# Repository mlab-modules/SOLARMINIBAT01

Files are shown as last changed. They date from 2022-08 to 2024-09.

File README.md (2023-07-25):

# SOLARMINIBAT01
<p float="left">
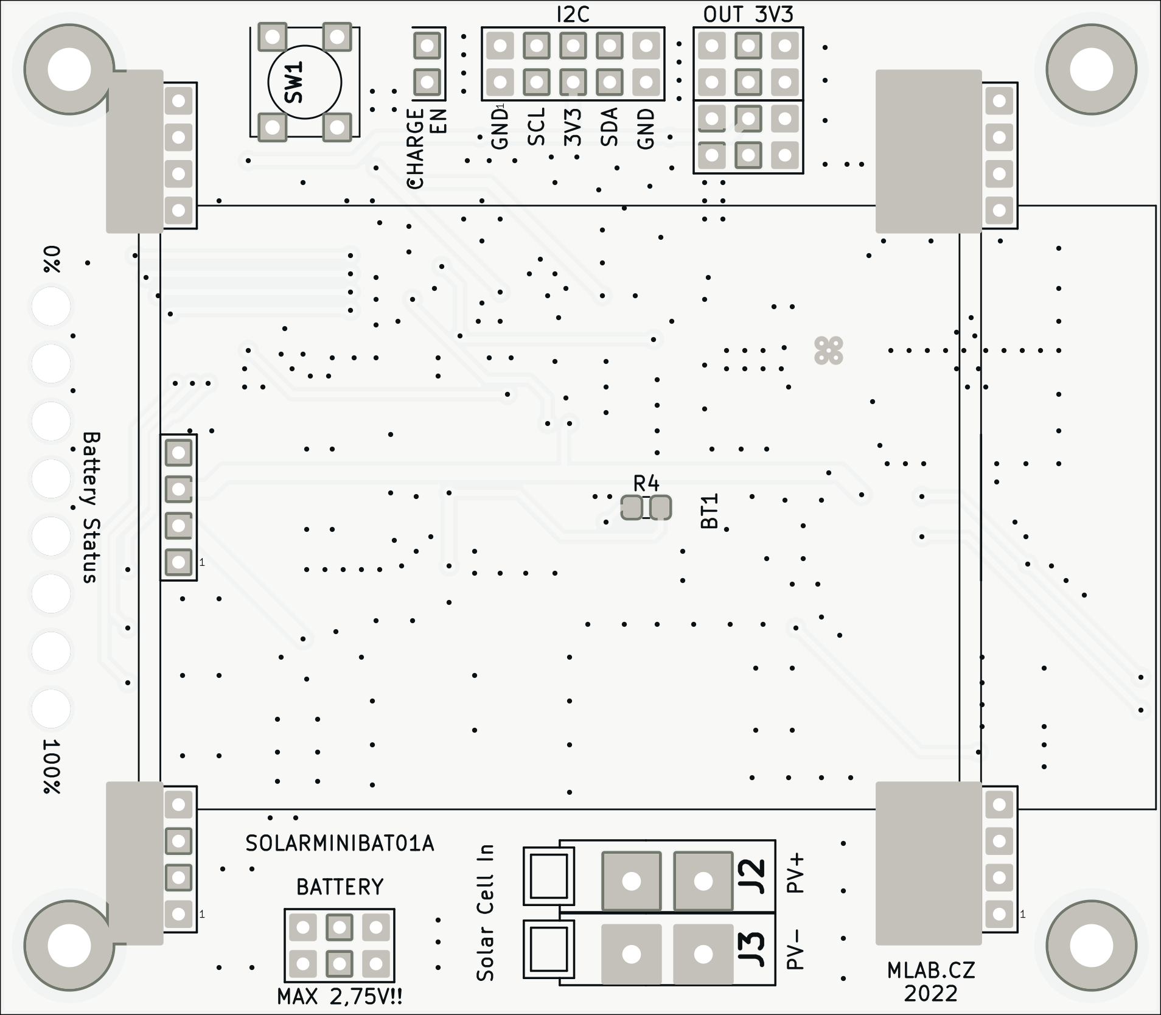
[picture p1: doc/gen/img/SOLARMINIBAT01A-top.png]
  
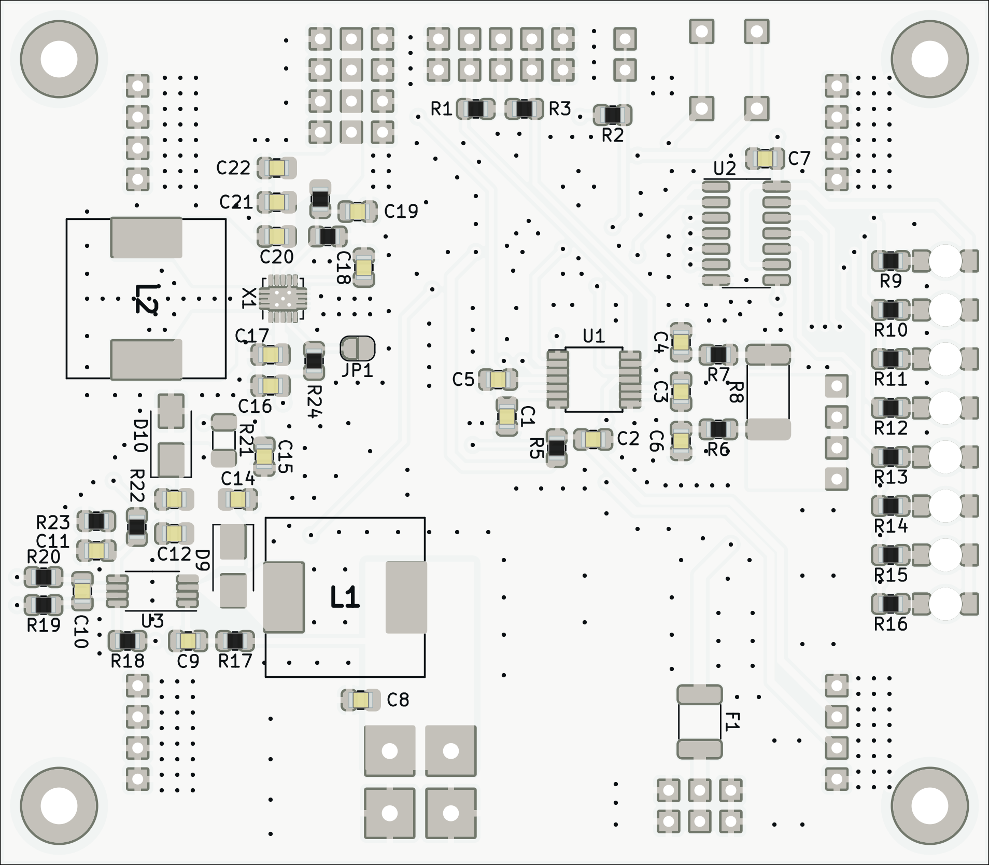
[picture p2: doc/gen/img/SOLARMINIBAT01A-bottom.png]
   
</p>

Battery module with [LTO cells](https://files.gwl.eu/inc/_doc/attach/StoItem/7015/GWL_LTO1865_Rechargeable.pdf). This module was primarily designed for use in autonomous outdoor devices powered by a solar cell. This is possible thanks to the use of LTO cells, which have a wide range of operating conditions and require minimal care. The device can therefore work in outdoor conditions all year round (tested in Central European conditions). 

### Features:
 * LTO batteries (4x LTO1865) cells
   * 1.3 Ah (per cell)
 * MPPT tracker for LTO batteries charging from solar cell
 * Battery gauge for battery charge state measurement
   * I2C interface
   * LED indication
 * Output switching voltage regulator
   *  Standard output voltage 3v3

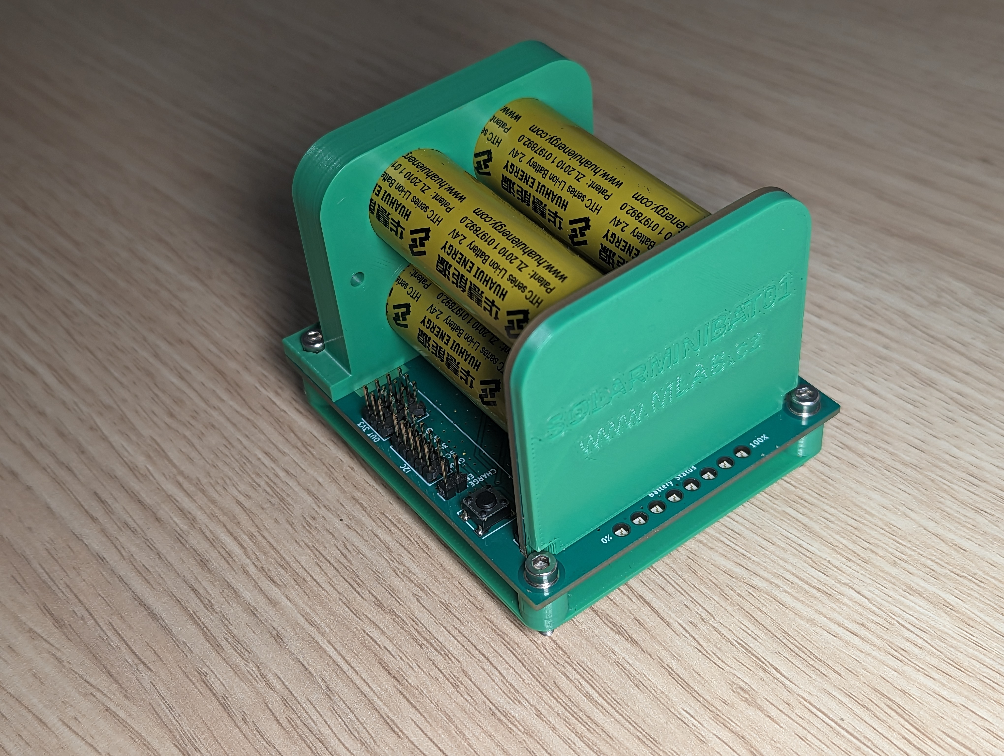
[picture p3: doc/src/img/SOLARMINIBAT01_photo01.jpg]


## Schematics


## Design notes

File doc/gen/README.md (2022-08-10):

# PCB

Board size: 80.77x70.61 mm (3.18x2.78 inches)

- This is the size of the rectangle that contains the board
- Thickness: 1.6 mm (63 mils)
- Material: FR4
- Finish: None
- Layers: 2
- Copper thickness: 35 µm

Solder mask: TOP / BOTTOM

- Color: Green

Silk screen: TOP / BOTTOM

- Color: White

Stackup:

| Name | Type | Color | Thickness | Material | Epsilon_r | Loss tangent |
|---|---|---|---|---|---|---|
| F.SilkS | Top Silk Screen | | | | | |
| F.Paste | Top Solder Paste | | | | | |
| F.Mask | Top Solder Mask | | 10 | | | |
| F.Cu | copper | | 35 | | | |
| dielectric 1 | core | | 1510 | FR4 | 4.5 | 0.02 |
| B.Cu | copper | | 35 | | | |
| B.Mask | Bottom Solder Mask | | 10 | | | |
| B.Paste | Bottom Solder Paste  | | | | | |
| B.SilkS | Bottom Silk Screen | | | | | |

# Important sizes

Clearance: 0.2 mm (8 mils)

Track width: 0.2 mm (8 mils)

- By design rules: 0.2 mm (8 mils)

Drill: 0.3 mm (12 mils)

- Vias: 0.5 mm (20 mils) [Design: 0.3 mm (12 mils)]
- Pads: 0.3 mm (12 mils)

Via: 0.89/0.5 mm (35/20 mils)

- By design rules: 0.4/0.3 mm (16/12 mils)
- Micro via: no [0.2/0.1 mm (8/4 mils)]
- Burried/blind via: no

Outer Annular Ring: 0.3 mm (12 mils)

- By design rules: 0.3 mm (12 mils)

Eurocircuits class: 4B

# General stats

Components count: (SMD/THT)

- Top: 1/13 (SMD + THT)
- Bottom: 62/2 (SMD + THT)

Defined tracks:

- 0.2 mm (8 mils)
- 0.3 mm (12 mils)
- 0.4 mm (16 mils)
- 0.5 mm (20 mils)
- 0.6 mm (24 mils)
- 0.7 mm (28 mils)
- 1.0 mm (39 mils)

Used tracks:

- 0.2 mm (8 mils) (24) defined: yes
- 0.3 mm (12 mils) (15) defined: yes
- 0.4 mm (16 mils) (218) defined: yes
- 0.5 mm (20 mils) (14) defined: yes
- 0.6 mm (24 mils) (71) defined: yes
- 1.0 mm (39 mils) (21) defined: yes

Defined vias:

Used vias:

- 0.89/0.5 mm (35/20 mils) (Count: 392, Aspect: 1.8 A) defined: no

Holes (excluding vias):

- 0.3 mm (12 mils) (5)
- 0.89 mm (35 mils) (50)
- 1.0 mm (39 mils) (4)
- 1.3 mm (51 mils) (4)
- 2.7 mm (106 mils) (8)
- 3.0 mm (118 mils) (4)

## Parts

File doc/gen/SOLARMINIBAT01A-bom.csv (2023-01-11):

Row | Description | Part | References | Value | Footprint | Quantity Per PCB | Status | Datasheet | UST_ID
1 | Single-cell battery | 4xLTO18650 | BT1 | 4xLTO18650 | 4XLTO1865V01A | 1 |  | ~
2 | Unpolarized capacitor | C | C19 | 10pF | C_0805_2012Metric | 1 |  | ~ | 5c70984712875079b91f8b30
3 | Unpolarized capacitor | C | C11 | 1nF | C_0805_2012Metric | 1 |  | ~ | 5c70984712875079b91f8b45
4 |  | C-RESCUE-LION2CELL01C | C5 | 3n3 | C_0805_2012Metric | 1 |  |  | 5c70984712875079b91f8b47
5 |  | C-RESCUE-LION2CELL01C | C1 C3 C4 C6 C7 | 100nF | C_0805_2012Metric | 5 |  |  | 5c70984712875079b91f8b4c
6 | Unpolarized capacitor | C | C9 C12 C18 | 100nF | C_0805_2012Metric | 3 |  | ~ | 5c70984712875079b91f8b4c
7 | Unpolarized capacitor | C | C10 | 1uF | C_0805_2012Metric | 1 |  | ~ | 5c70984712875079b91f8b50
8 |  | C-RESCUE-LION2CELL01C | C2 | 1uF | C_0805_2012Metric | 1 |  |  | 5c70984712875079b91f8b50
9 | Unpolarized capacitor | C | C13 C17 C20 | 10uF/6V3 | C_0805_2012Metric | 3 |  | ~ | 5c70984712875079b91f8b53
10 | Unpolarized capacitor | C | C8 C14 C15 C16 C21 C22 | 47uF/6V3 | C_0805_2012Metric | 6 |  | ~ | 60d580ff1287500165f8595a
11 | Schottky diode | D_Schottky | D9 | 15MQ040N | D_SMA | 1 |  | https://eu.mouser.com/datasheet/2/427/vs_15mq040ntrpbf-1769271.pdf | 5c70984512875079b91f88b0
12 |  | LED-RESCUE-LION2CELL01C | D1 D2 D3 D4 D5 D6 D7 D8 | ORAGE | LED_1206 | 8 |  |  | 5c70984412875079b91f8897
13 | Zener diode | D_Zener | D10 | SMBJ5.0A | D_SMA | 1 |  | ~ | 5c70984512875079b91f88c7
14 | Resettable fuse, polymeric positive temperature coefficient | Polyfuse | F1 | 1,1A | Fuse_1812_4532Metric_Pad1.30x3.40mm_HandSolder | 1 |  | ~ | 5c70984512875079b91f88d3
15 | 2x01 2.54 mm pitch header, 2 pins next to each other are connected | HEADER_2x01_PARALLEL | J4 | HEADER_2x01_PARALLEL | Straight_2x01 | 1
16 | 2x03 2.54 mm pitch header, 2 pins next to each other are connected | HEADER_2x03_PARALLEL | J1 J5 J6 | HEADER_2x03_PARALLEL | Straight_2x03 | 3
17 | Symbole general de connecteur | CONN1_1 | J3 | WAGO 256 BLUE | WAGO256 | 1 |  |  | 5c70984412875079b91f87c3
18 | Symbole general de connecteur | CONN1_1 | J2 | WAGO 256 ORANGE | WAGO256 | 1 |  |  | 5c70984412875079b91f87c4
19 | Inductor, small symbol | L_Small | L1 | 10uH - DE1205-10 | DE1205-10 | 1 |  | https://www.tme.eu/Document/d1f8b47d020ebf11f3b92c6891638dfa/de.pdf | 5c70984412875079b91f8822
20 | Inductor, small symbol | L_Small | L2 | DE1207-1 | DE1205-10 | 1 |  | ~ | 5c70984412875079b91f8823
21 | 2x05 2.54 mm pitch header, 2 pins next to each other are connected | HEADER_2x05_PARALLEL | P1 | HEADER_2x05_PARALLEL | Straight_2x05 | 1
22 | Resistor | R | R21 | 0R | R_1206_3216Metric | 1 |  | ~ | 5c70984712875079b91f8aaf
23 |  | R-RESCUE-LION2CELL01C | R8 | 0R01 75PPM | R_2512_6332Metric_Pad1.40x3.35mm_HandSolder | 1 |  |  | 5c70984712875079b91f8abf
24 |  | R-RESCUE-LION2CELL01C | R6 R7 | 100R | R_0805_2012Metric | 2 |  |  | 5c70984512875079b91f8977
25 |  | R-RESCUE-LION2CELL01C | R9 R10 R11 R12 R13 R14 R15 R16 | 270R | R_0805_2012Metric | 8 |  |  | 5c70984512875079b91f8983
26 | Resistor | R | R17 R18 R19 R20 | 1k | R_0805_2012Metric | 4 |  | ~ | 5c70984512875079b91f898c
27 |  | R-RESCUE-LION2CELL01C | R5 | 1k | R_0805_2012Metric | 1 |  |  | 5c70984512875079b91f898c
28 | Resistor | R | R24 | 10k | R_0805_2012Metric | 1 |  | ~ | 5c70984612875079b91f899f
29 |  | R-RESCUE-LION2CELL01C | R4 | 10K NTC | R_0805_2012Metric_Pad1.20x1.40mm_HandSolder | 1 |  |  | 5c70984712875079b91f8ac5
30 |  | R-RESCUE-LION2CELL01C | R1 R2 R3 | 47k | R_0805_2012Metric | 3 |  |  | 5e3ffaff1287502a33bad825
31 | Resistor | R | R23 R26 | 100k | R_0805_2012Metric | 2 |  | ~ | 5c70984712875079b91f8a96
32 | Resistor | R | R22 | 110k | R_0805_2012Metric | 1 |  | ~ | 5e3ffc4a1287502a33bad850
33 | Resistor | R | R25 | 560k | R_0805_2012Metric | 1 |  | ~ | 5c70984712875079b91f8aa6
34 |  | SW_PUSH | SW1 | SW_PUSH | SW_PUSH_SMALL | 1 |  |  | 5c70984712875079b91f8ad1
35 |  | BQ34Z100 | U1 | BQ34Z100 | TSSOP-14_4.4x5mm_Pitch0.65mm | 1 |  | https://www.ti.com/lit/ds/symlink/bq34z100-g1.pdf | 5c70984612875079b91f89c3
36 |  | SN74HC164D | U2 | SN74HC164D | SO-14_3.9x8.65mm_P1.27mm | 1 |  |  | 5c70984612875079b91f89ed
37 | High efficiency solar battery charger with embedded MPPT | SPV1040 | U3 | SPV1040 | TSSOP-8_4.4x3mm_P0.65mm | 1 |  | https://www.st.com/resource/en/datasheet/spv1040.pdf | 5c70984612875079b91f89bc
38 | Buck-Boost Converter, 2.5-12V Input Voltage, 2-A Switch Current, Adjustable 2.5-8V Output Voltage, S-PWSON-N10 | TPS63060 | X1 | TPS63060 | Texas_S-PWSON-N10_ThermalVias | 1 |  | http://www.ti.com/lit/ds/symlink/tps63060.pdf | 5c70984612875079b91f89c2
Project info:
Schematic: | SOLARMINIBAT01A
Variant: | default
Revision: | A
Date: | 2022-07-20
KiCad Version: | 6.0.4-6f826c9f35~116~ubuntu20.04.1
Statistics:
Component Groups: | 38
Component Count: | 74
Fitted Components: | 74
Number of PCBs: | 1
Total Components: | 74

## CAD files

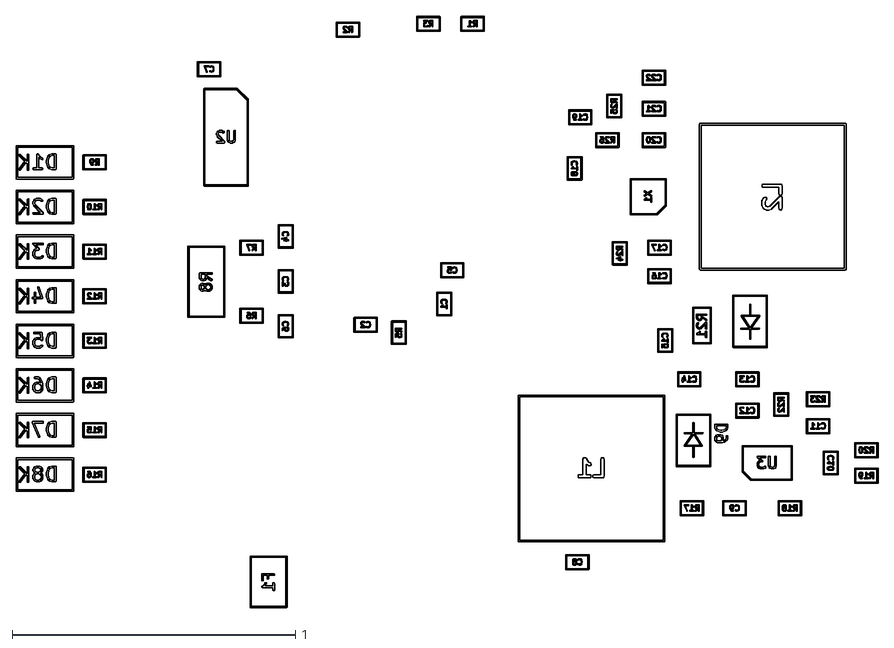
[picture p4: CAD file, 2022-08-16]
doc/gen/dxf/SOLARMINIBAT01A-B_Fab.dxf
3.04 x 2.09

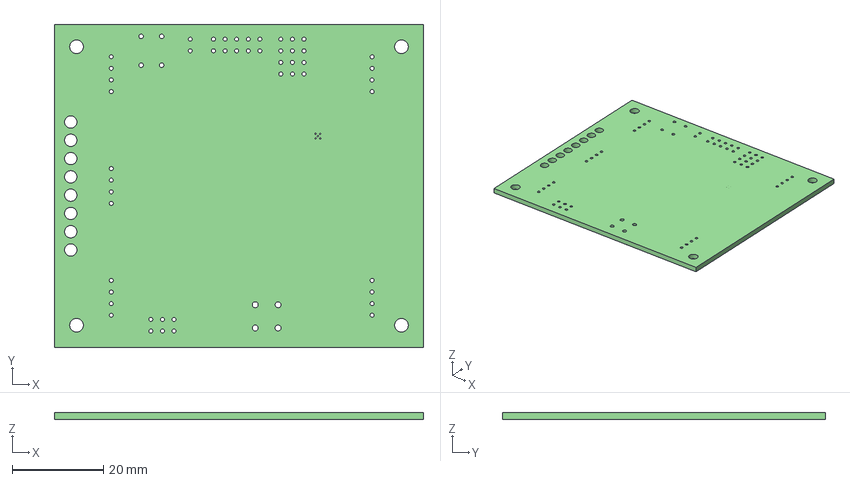
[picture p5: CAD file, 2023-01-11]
doc/gen/SOLARMINIBAT01A.step
80.8 x 70.6 x 1.60 mm

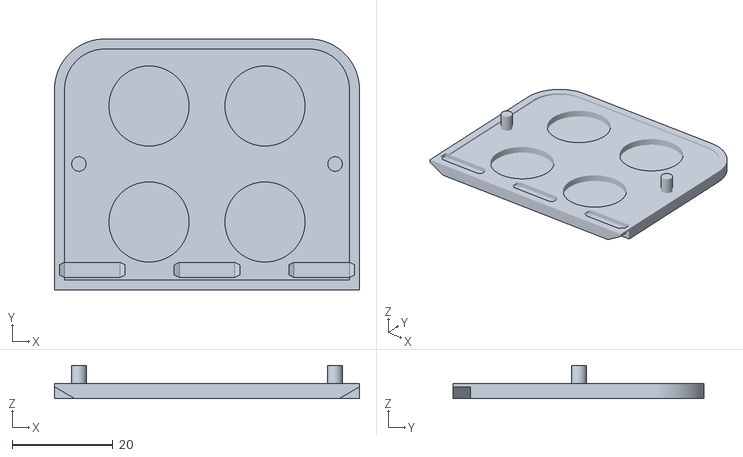
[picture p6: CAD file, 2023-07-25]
hw/cad/stl/battery_cover.stl
60.5 x 49.8 x 6.60

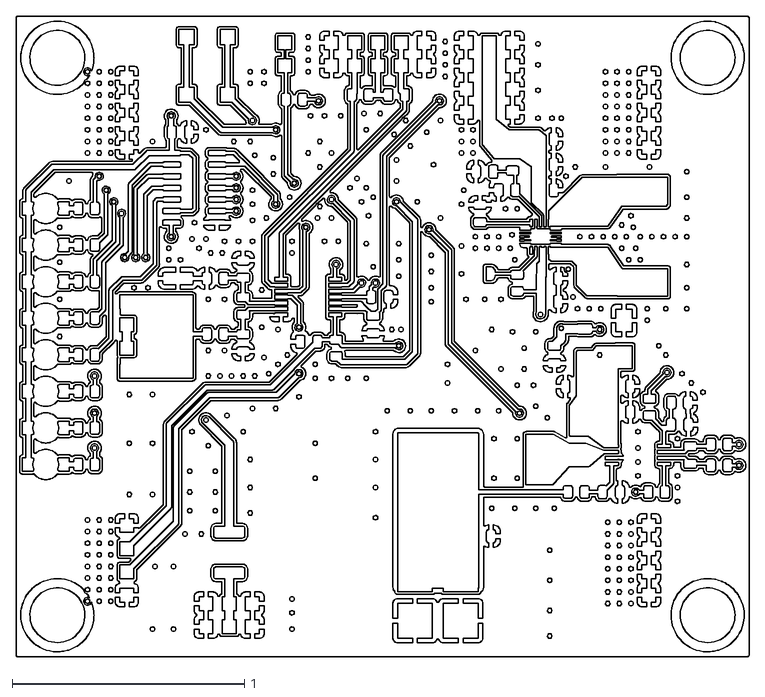
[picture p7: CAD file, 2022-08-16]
doc/gen/dxf/SOLARMINIBAT01A-B_Cu.dxf
3.16 x 2.76

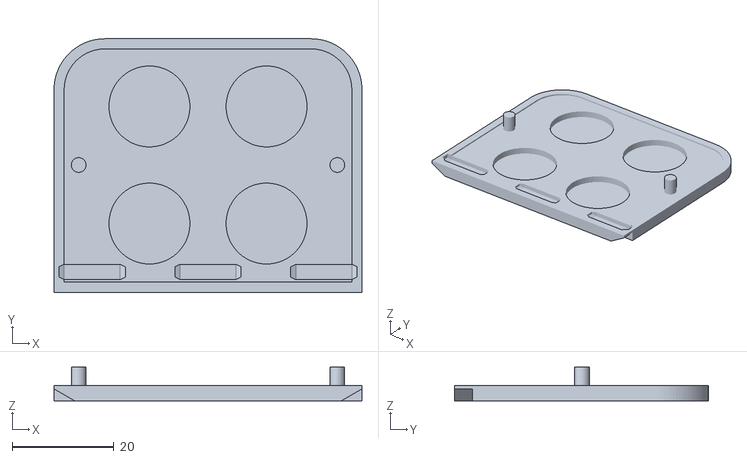
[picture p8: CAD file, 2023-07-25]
hw/cad/stl/battery_cover_text.stl
60.5 x 49.8 x 6.60

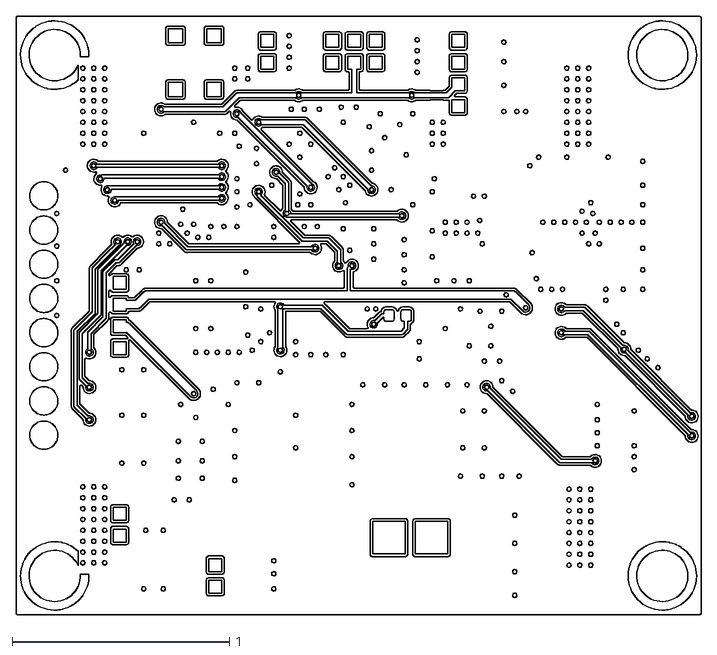
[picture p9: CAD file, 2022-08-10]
doc/gen/dxf/SOLARMINIBAT01A-F_Cu.dxf
3.16 x 2.76

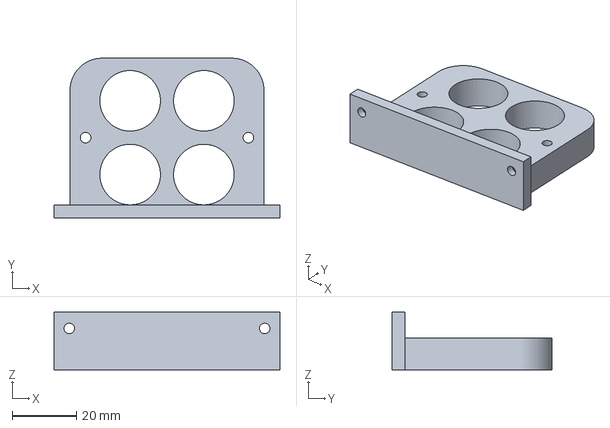
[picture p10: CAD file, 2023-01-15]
hw/cad/stl/battery_holder.3mf
70.5 x 49.8 x 18.0 mm

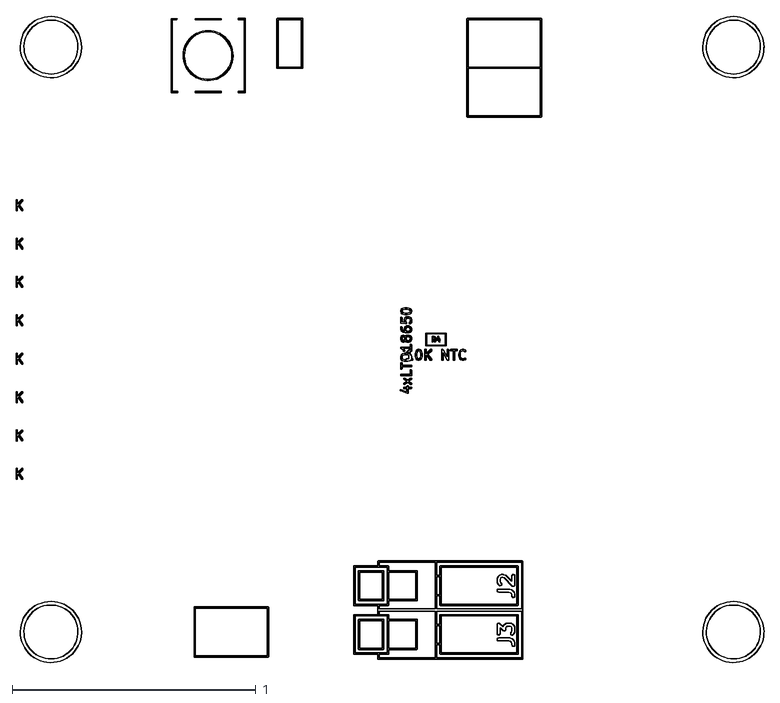
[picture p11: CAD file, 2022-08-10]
doc/gen/dxf/SOLARMINIBAT01A-F_Fab.dxf
3.07 x 2.65

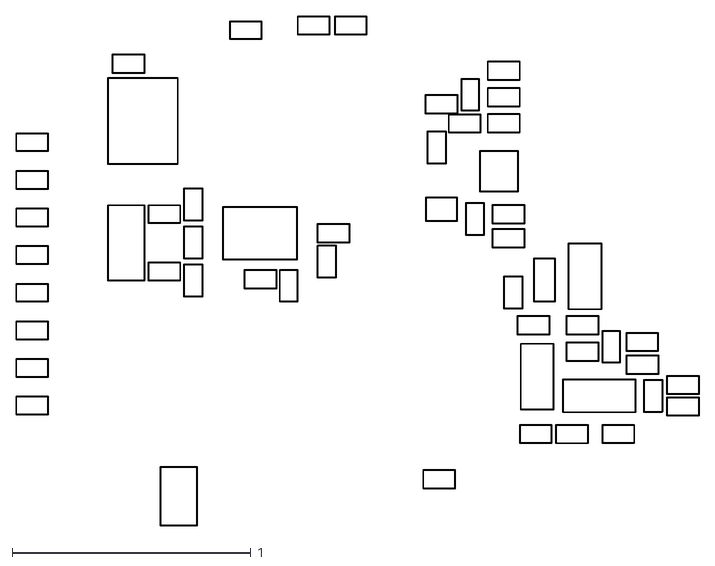
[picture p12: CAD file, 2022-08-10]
doc/gen/dxf/SOLARMINIBAT01A-B_Courtyard.dxf
2.86 x 2.13

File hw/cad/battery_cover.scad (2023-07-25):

$fn=100;

base_width = 70.5;
pcb_width = 60.5;


pcb_height = 49.8;
pcb_radius = 10;

pcb_screw_dist = 10.16*6;
screw_from_side = 10.16*0.5;

flange_thickness = 4;
flange_screw_depth =  2.5;
holder_depth = 3;
flange_depth = holder_depth+8;


bat_bot_z = 13.5;
bat_dist = 23;

battery_d = 18.9-3;

mount_screw_d = 10.16*5;
mount_screw_z = 25;

M3_screw_diameter = 2.9;
M3_nut_diameter = 6.6;

text = 0;

module battery_holder(){
difference(){
union(){
    hull(){
        translate([pcb_width/2-pcb_radius, pcb_height-pcb_radius, 0])
            cylinder(r = pcb_radius, h = holder_depth);

        translate([-1*(pcb_width/2-pcb_radius), pcb_height-pcb_radius, 0])
            cylinder(r = pcb_radius, h = holder_depth);
        
        translate([-pcb_width/2, 0, 0])
            cube([pcb_width, 1, holder_depth]);
    }
    //translate([-base_width/2, 0, 0])
    //    cube([base_width, flange_thickness, flange_depth]);
}

    
    if(1) translate([0, 0, holder_depth-0.4]) hull(){
        translate([pcb_width/2-pcb_radius, pcb_height-pcb_radius, 0])
            cylinder(r = pcb_radius-2, h = holder_depth);

        translate([-1*(pcb_width/2-pcb_radius), pcb_height-pcb_radius, 0])
            cylinder(r = pcb_radius-2, h = holder_depth);
        
        translate([-pcb_width/2+2, 2, 0])
            cube([pcb_width-4, 1, holder_depth]);
    }
    
    for(x = [-pcb_screw_dist/2, pcb_screw_dist/2]) translate([x, flange_screw_depth, flange_depth-screw_from_side]) rotate([-90, 0, 0]){
              cylinder(d=M3_screw_diameter, h=20, $fn=20, center=true);
              cylinder(d = M3_nut_diameter, h = 10, $fn=6);
        }
    
    for(x=[-0.5, 0.5], y=[0, 1]) translate([bat_dist*x, bat_dist*y+bat_bot_z, holder_depth-2]) cylinder(d = battery_d, h = 2, $fn=60);
    
    
    for(x=[-1, 0, 1]) translate([x*22.75, 4, holder_depth]) hull(){
            cube([11, 3, 3], center=true);
            cube([13, 2, 2], center=true);
        }
    
    for(x=[-1, 1]) translate([x*32.2,0,0]) rotate([0, 60*x, 0]) cube([6, 7, 15], center=true);
    
    
    
    if(text){
        translate([0, 28, 0.2]) rotate([0, 180, 0]) linear_extrude(0.2) text("SOLARMINIBAT01", halign="center", size=4.5);
        translate([0, 20, 0.2]) rotate([0, 180, 0]) linear_extrude(0.2) text("www.MLAB.cz", halign="center", size=4.5);
    }
    
}

for(x=[-0.5, 0.5]) translate([mount_screw_d*x, mount_screw_z, 0]) cylinder(d = M3_screw_diameter, h = holder_depth+1.6+2, $fn=60);


}




battery_holder();

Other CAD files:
doc/gen/dxf/SOLARMINIBAT01A-User_Eco1.dxf
doc/gen/dxf/SOLARMINIBAT01A-User_3.dxf
doc/gen/dxf/SOLARMINIBAT01A-User_7.dxf
doc/gen/dxf/SOLARMINIBAT01A-User_9.dxf
doc/gen/dxf/SOLARMINIBAT01A-User_1.dxf
doc/gen/dxf/SOLARMINIBAT01A-User_Drawings.dxf
doc/gen/dxf/SOLARMINIBAT01A-User_8.dxf
doc/gen/dxf/SOLARMINIBAT01A-Margin.dxf
doc/gen/dxf/SOLARMINIBAT01A-User_6.dxf
hw/cad/battery_holder.scad
doc/gen/dxf/SOLARMINIBAT01A-B_Adhesive.dxf
doc/gen/dxf/SOLARMINIBAT01A-B_Mask.dxf
doc/gen/dxf/SOLARMINIBAT01A-B_Paste.dxf
doc/gen/dxf/SOLARMINIBAT01A-B_Silkscreen.dxf
doc/gen/dxf/SOLARMINIBAT01A-Edge_Cuts.dxf
doc/gen/dxf/SOLARMINIBAT01A-F_Adhesive.dxf
doc/gen/dxf/SOLARMINIBAT01A-F_Courtyard.dxf
doc/gen/dxf/SOLARMINIBAT01A-F_Mask.dxf
doc/gen/dxf/SOLARMINIBAT01A-F_Paste.dxf
doc/gen/dxf/SOLARMINIBAT01A-F_Silkscreen.dxf
doc/gen/dxf/SOLARMINIBAT01A-User_2.dxf
doc/gen/dxf/SOLARMINIBAT01A-User_4.dxf
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

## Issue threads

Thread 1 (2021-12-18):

Design requirements

kaklik, 2021-12-18:
Napájecí modul má řešit běžné požadavky napájení zařízení typu  GEODOS, automatická meteostanice, nebo jiná měřící zařízení v terénu se spotřebou pod 4W. Modul se musí vypořádat s částečným zastíněním fotovoltaických panelů nebo velkými změnami teplot.

Pro nabájení se předpokládá fotovoltaický panel s následujícími parametry:
- Isc = 2,3 A
- Voc= 2,5 V
- Impp= 2,1 A
- Vmpp= 2,1 V
- Pm= 4,4 Wp

Konstrukčně bude vycházet z původní realizace napájení založeného na Li-ion článku velikosti 18650, které se skládalo z několika MLAB modulů.

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

Hlavním problémem této sestavy je nutnost použití nabíjecího měniče pro lion-článek, který jednak zajišťuje omezení dobíjecího proudu podle stupně nabití článku a také zajišťuje blokování nabíjení za mrazu. Výsledkem obou těchto omezení je snížení rychlosti nabíjení akumulátoru, případně jeho nedobíjení za trvale mrazivých podmínek. Řešením těchto potíží by mělo být použití akumulátoru s chemií [LTO](https://files.gwl.eu/inc/_doc/attach/StoItem/7015/GWL_LTO1865_Rechargeable.pdf), která umožňuje nabíjení za nízkých teplot a nabíjení vysokými nabíjecími proudy až do maximálního napětí (díky značné toleranci přepětí oproti li-ion).
Otázkou je reálná potřeba omezení nabíjení za mrazu neboť  LTO akumulátor lze nabíjet i do ‐15 °C. Je tak na diskusi, zda blokování nabíjení je potřeba řešit. Alternativně by bylo možné takovou logiku vyřešit digitálním termostatem s přepínačem, který by přebytečný vstupní výkon přesměroval do vyhřívání.

Nově by vlastnosti všech těchto modulů měly být sloučeny do jednoho modulu. Konkrétně jde zejména o funkce:

- MPPT pro solární panel
- Omezení nabíjecího napětí akumulátoru na 2.75 V
- Měření a indikace stavu akumulátoru
- Příprava stabilního napájení 3V3 pro následující elektroniku

MPPT je na základě [průzkumu v souvislosti se zařízením GEODOS](https://github.com/UniversalScientificTechnologies/GEODOS01/issues/1#issuecomment-996991895) zřejmě stále nejlepší řešit obvodem [SPV1040](https://www.st.com/en/power-management/spv1040.html), který obsahuje současný modul [SOLARMINI](https://github.com/mlab-modules/SOLARMINI01). Jeho schéma je ale ale potřeba ověřit proti aktualizovanému datasheetu.  Stejný obvod musí zajistit omezení nabíjecího napětí akumulátoru na 2.75 V.

Měření a indikace stavu zřejmě  může být řešena stejným obvodem jako nyní je v LION1CELL [bq34z100](https://e2e.ti.com/support/power-management-group/power-management/f/power-management-forum/329276/bq34z100-and-bq77910-for-lithium-titanate-oxide-cells).

Jde tak o toto zapojení ve kterém je potřeba zkontrolovat zda mu stačí pracovní napětí 2.5V. Povolený rozsah napetí na LTO článku totiž je 1.50 V až 2.80V

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
Ostatní části zapojení z modulu LION1CELL je tak možné odebrat. Neboť články není potřeba chránit před zkratem, protože jedinným napájecím výstupem bude výstup měniče, viz dále.  Ochrana proti přepětí je naopak zajištěna vstupním měničem a články jsou proti přepětí částečně odolné.

Napěťový rozsah samotného LTO článku je nevhodný pro použití v napájených modulech. Neboť nejde o žádné standardní napětí. Je proto nutné na výstup modulu zapojit měnič. Lze použít buď stejný měnič  [tps63036](https://www.ti.com/lit/ds/symlink/tps63036.pdf), který měl být původně použit v modulu LION1CELL ale [díky chybě na PCB nikdy nefungoval](https://github.com/mlab-modules/LION1CELL01/issues/1). Nebo použít stejný měnič, jako je v modulu [TPS63060V01](https://github.com/mlab-modules/TPS63060V01). Oba tyto měniče mají undervoltage lockout přibližně na hodnotě 1.8V. Tím dojde k vypnutí měniče bezpečně dříve, než bude akumulátor vybit na kritickou hodnotu.

## Mechanická konstrukce

Mechanická konstrukce modulu v tomto případě má dvě možná řešení. Jedním je montáž článků do svislé polohy stejně jako přímá montáž THT elektrolytických kondenzátorů. Toto řešení má nepříjemnou vlastnost, že vestavná výška je pak díky rozměrům článků 65mm nad PCB.  Takový konstrukční rozměr může zkomplikovat používání tohoto modulu.

Druhým řešením pak je použít dvojici nebo čtveřici článků, která bude k modulu připojena na ležato. V takovém případě za užití čtveřice článků byla 38mm nad PCB.  Čtveřici článků spojených paralelně by ale k modulu bylo nutné nějakým způsobem připojit. Jedním z řešení je návrh samostatného PCB, který by se následně k modulu přiletoval vertikálně i společně se zaletovanou čtveřicí akumulátorů, které by na modulu ležely na bok.

Rozhodnutí o obou těchto konstrukčnich možnostech zřejmě vyplyne z velikosti samotného návrhu modulu.

kaklik, 2022-01-28:
Na mechanickou konstrukci mají možná vliv podmínky pro leteckou přepravu akumulátorů.  Bylo by potřeba ověřit, co musí modul splňovat, aby bylo možné jej posílat zamontovaný v zařízení leteckou přepravou.

kakl, 2022-10-02:
delic v solarmini je 100:110 k ohm
dava to 2,77 V naprazdno
R7 = 110 k
R8 = 100 k

kakl, 2022-10-02:
R7 = 100 k
R8 = 91 k
dava 2,76 V, to je jeste lepsi

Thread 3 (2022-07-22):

Battery dimensions

ChroustJan, 2022-07-22:
Rozměry článku. Rozteč vývodů 7,5mm a průměr vývodu 0,96mm. Průměr baterie 18,74mm a délka bez vývodů 65,76mm.

Closed 2022-08-10.

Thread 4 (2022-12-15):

DC output dropouts

kaklik, 2022-12-15:
Vypadá to, že aktuální implementace s měničem v MLAB modulu vytváří výpadky.
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

kaklik, 2023-01-11:
Podle zjištění o @kakl  za tyhle výpadky může spíše vypadávající přenos dat.

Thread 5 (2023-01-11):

Remove battery connector

kaklik, 2023-01-11:
In the next revision remove battery connector J1 and fuse F1. That component allows direct access to cells, which probably results in cell damage.

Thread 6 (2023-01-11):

Solar Panel input connector

kaklik, 2023-01-11:
Rename "Solar Cell In" to "Solar Panel In".
Also, note that the maximum input voltage to the module from the photovoltaic panel is 2.80V.
Explicitly the maximum input voltage is 2.8V + D9 dropout. But the [diode dropout ](https://eu.mouser.com/datasheet/2/427/vs_15mq040ntrpbf-1769271.pdf )depends on the temperature and current. Therefore it is better to neglect it.

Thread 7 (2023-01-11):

Module config initialization

kaklik, 2023-01-11:
Actually the fuel gauge IC needs to be configured and rebooted before permanent connection to the cells.  The probably best way how to do that is to solder the cells with disabled output DC/DC converter. Then enable 3.3V converter X1 to supply fuel gauge IC U1.
In the current design is hard to do that because enable pin of X1 is permanently connected to the input power. The better solution should be to use a solder bridge, which could be soldered after the soldering of the input cell battery and after configuring the fuel gauge firmware parameters.

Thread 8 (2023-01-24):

Correct gas gauge parameters setup

kaklik, 2023-01-24:
@kakl  našel postup, jak ziskat chemistry ID pro guage https://www.ti.com/lit/an/slva725a/slva725a.pdf
chce to tu nasi nabijecku, zmerit jeden vybijeci a jeden nabijeci cyklus, to se zazipuje a uploadne na TI web a do hodiny by melo prijit chemistry ID
Tady je postup: https://www.ti.com/tool/GPCCHEM#description

roman-dvorak, 2023-07-25:
Soubor, který naměřil @kakl  je needostatečný. TI vyžaduje více souborů (viz odpověď v emailu). Je tedy potřeba více prozkoumat jejich potřeby:

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

Naměřená data vypadají takto:
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

Naměřené CSV: [lto.log](https://github.com/mlab-modules/SOLARMINIBAT01/files/12159693/lto.log)

roman-dvorak, 2023-07-25:
Po převedení logu do správného formátu a doplnění o metadata přišel takovýto report:

```
0	0	0
0	0	0
0	0	0
0	0	0
0	0	0
0	0	0
0	0	0
0	0	0
0	0	0
0	0	0
0	0	0
0	0	0
0

Summary of all IDs with max. DOD deviation below 3%

Chem ID	max DOD error, %	Max R deviation, ratio
0	0	0

Warning: Deviation is above recommended level. New chem ID needs to be released for this cell. Please contact your TI representative to send the cell to Dallas for characterization

Selection of best generic ID for ROM based devices like bq274xx

Device / Family #1
Generic Chem ID	Device/ Voltage/ Chemistry	max DOD error, %
312	bq27421-G1B: 4.3V LiCoO2	200
354	bq27411-G1C: 4.35V LiCoO2	200
3142	bq27421-G1D: 4.4V LiCoO2	200
128	bq27421-G1A: 4.2V LiCoO2	200
Best generic ID 312
Warning: Generic ID Deviation is so high that it is most likely due to anomaly in the data. Please check that data files have recomended format, units and test schedule

Device / Family #2
Generic Chem ID	Device/ Voltage/ Chemistry	max DOD error, %
1210	bq27621:  (ALT_CHEM1) 4.3V LiCoO2	200
354	bq27621:  (ALT_CHEM2) 4.35V LiCoO2	200
1202	bq27621: (default) 4.2V LiCoO2	200
Best generic ID 1210
Warning: Generic ID Deviation is so high that it is most likely due to anomaly in the data. Please check that data files have recomended format, units and test schedule

Device / Family #3
Generic Chem ID	Device/ Voltage/ Chemistry	max DOD error, %
3230	bq27426: (default) 4.35V LiCoO2	100
3142	bq27426: (ALT-CHEM2) 4.4V LiCoO2	200
1202	bq27426: (ALT_CHEM1) 4.2V LiCoO2	200
Best generic ID 3230
Warning: Generic ID Deviation is so high that it is most likely due to anomaly in the data. Please check that data files have recomended format, units and test schedule

Warning: First OCVpoint has non-zero current I=  -0.01 Please make sure you have a 2 hr relaxation period before the beginning of discharge.
Warning: Last OCVpoint has non-zero current I=  -0.016 Please make sure you have a 5 hr relaxation period after the end of discharge.
Warning: Discharge rate is too high. High rate reduces ID detection accuracy	 10 hr rate is recomeended. Total discharge time is less than 5 hrs	 t_hrs=  3.64923638888889
```

Zaslaná data jsou: [lto.zip](https://github.com/mlab-modules/SOLARMINIBAT01/files/12161319/lto.zip)
Report: [lto-report.zip](https://github.com/mlab-modules/SOLARMINIBAT01/files/12161321/lto-report.zip)

Rozpoznání chemie tedy není moc úspěšné. Nebylo dodrženo několik požadavků na zdrojová data. Třeba vysoká rychlost vybíjení nebo krátké ustálení napětí na konci měření.

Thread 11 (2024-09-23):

Increase capacitance on MPPT charger input

kaklik, 2024-09-23:
The input capacitance seems insufficient for a case of low light on the panel and longer wires to the PV panel. The voltage converter does not start properly under this conditions.

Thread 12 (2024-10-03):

Maximum cell voltage

kaklik, 2024-10-03:
delic v solarmini je 100:110 k ohm
dava to 2,69 V az 2,77 V naprazdno pri 1 % odporech
R7 = 110 k
R8 = 100 k

_Originally posted by @kakl in https://github.com/mlab-modules/SOLARMINIBAT01/issues/1#issuecomment-1264584458_

kaklik, 2024-10-03:
Podle mých dosavadních experimentů na dvou kusech SOLARMINIBAT je tohle nastavení zřejmě neoptimální. Protože v zřejmě důsledku tolerance VCRTL (1.2 až 1.3V) je na článku pozorovatelné i nízké napětí pod 2.5 V.

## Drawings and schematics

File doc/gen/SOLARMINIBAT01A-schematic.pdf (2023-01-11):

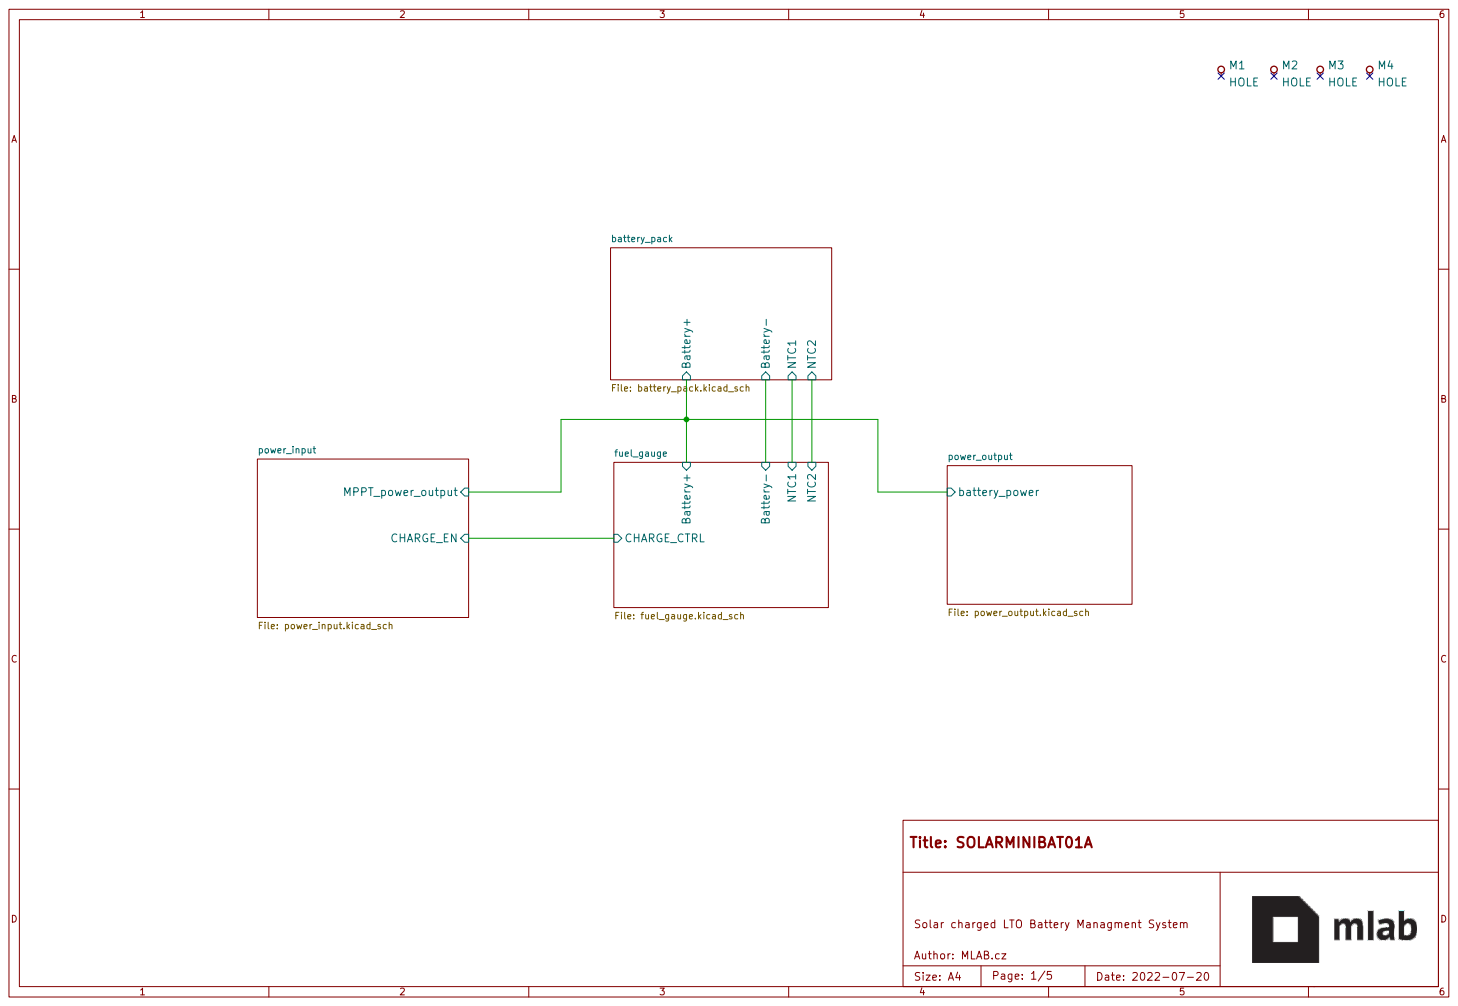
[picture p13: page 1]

Solar charged LTO Battery Managment System

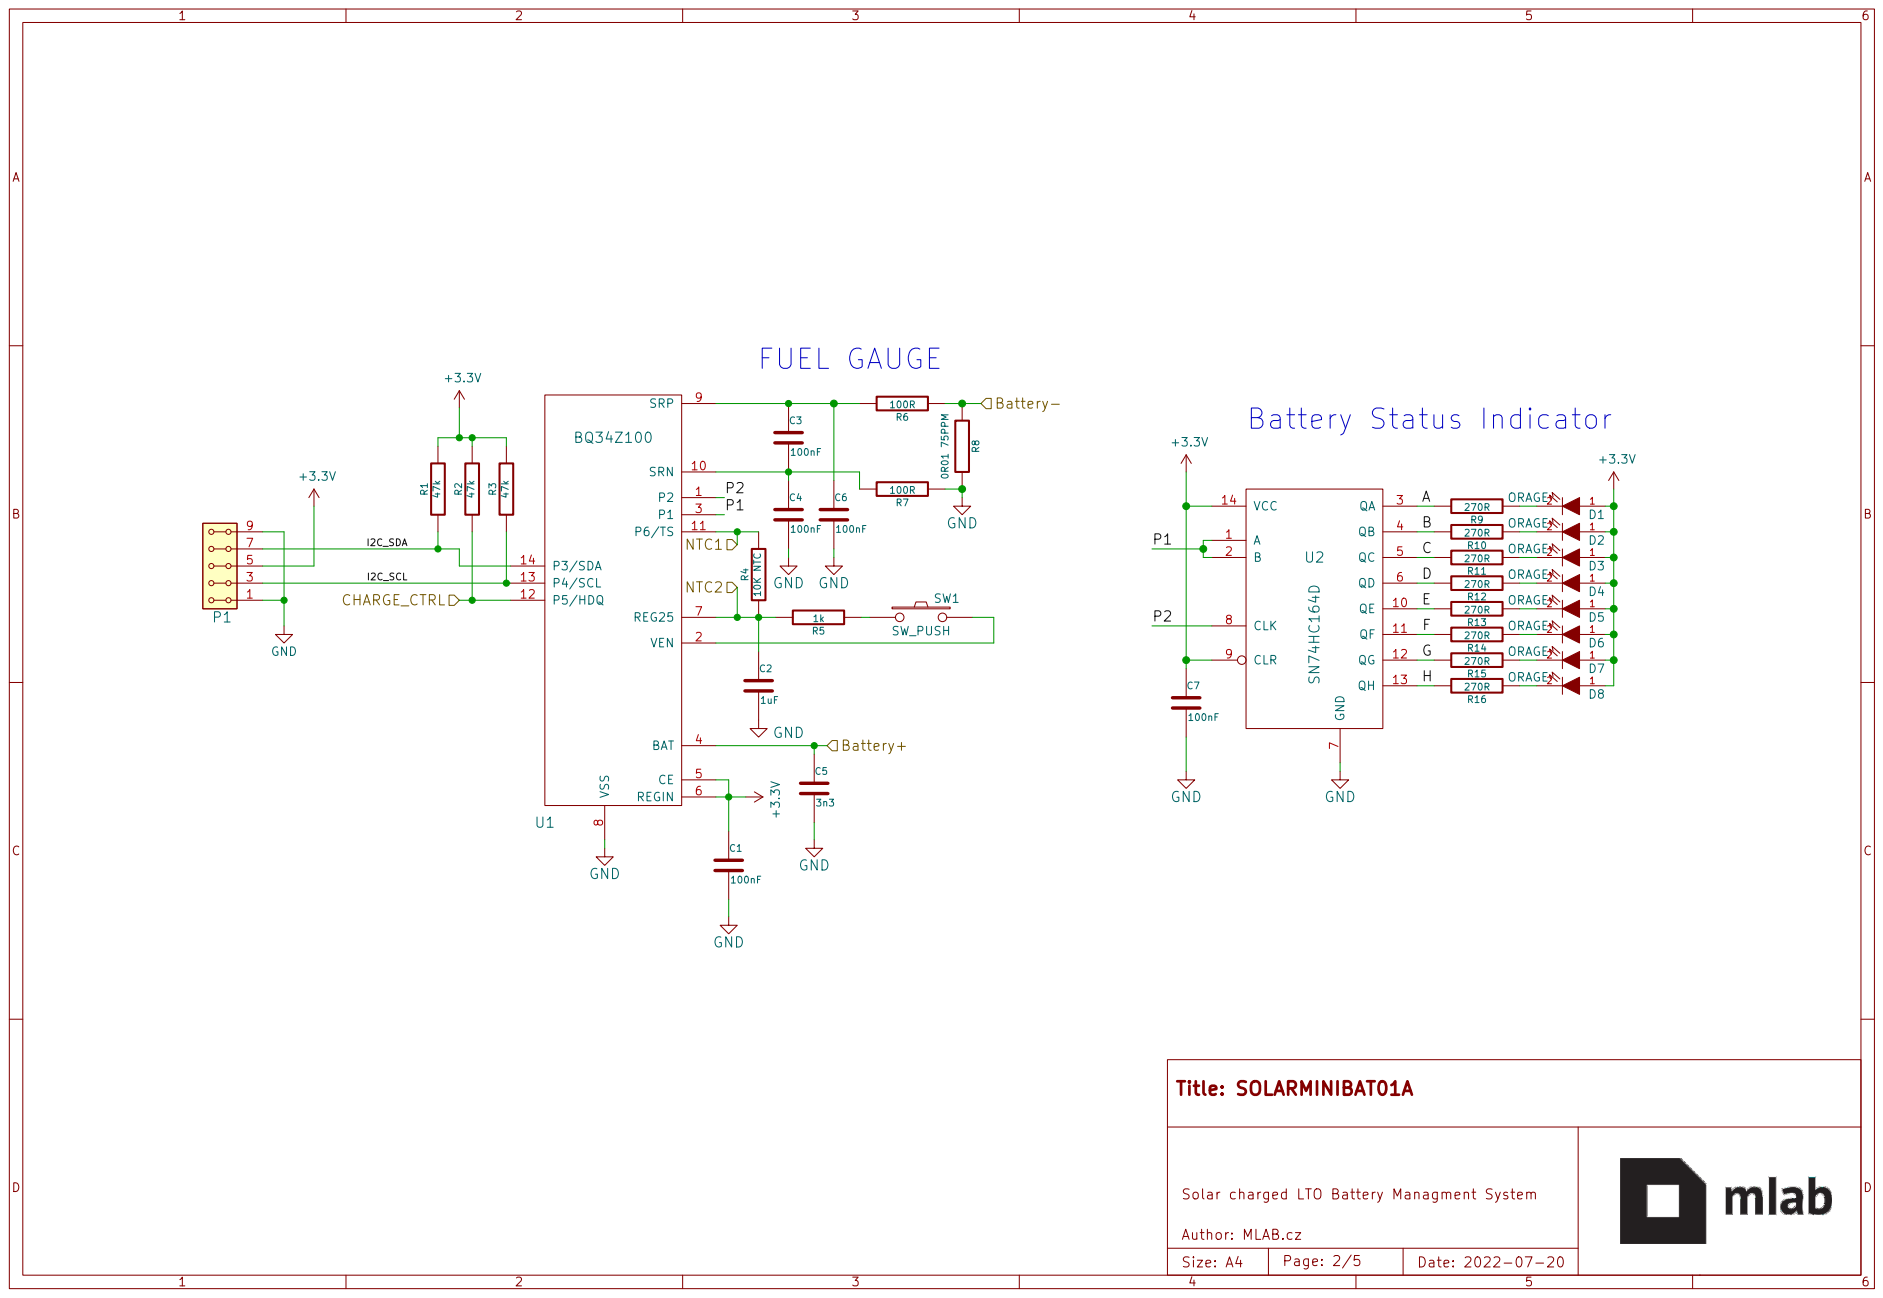
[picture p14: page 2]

Solar charged LTO Battery Managment System

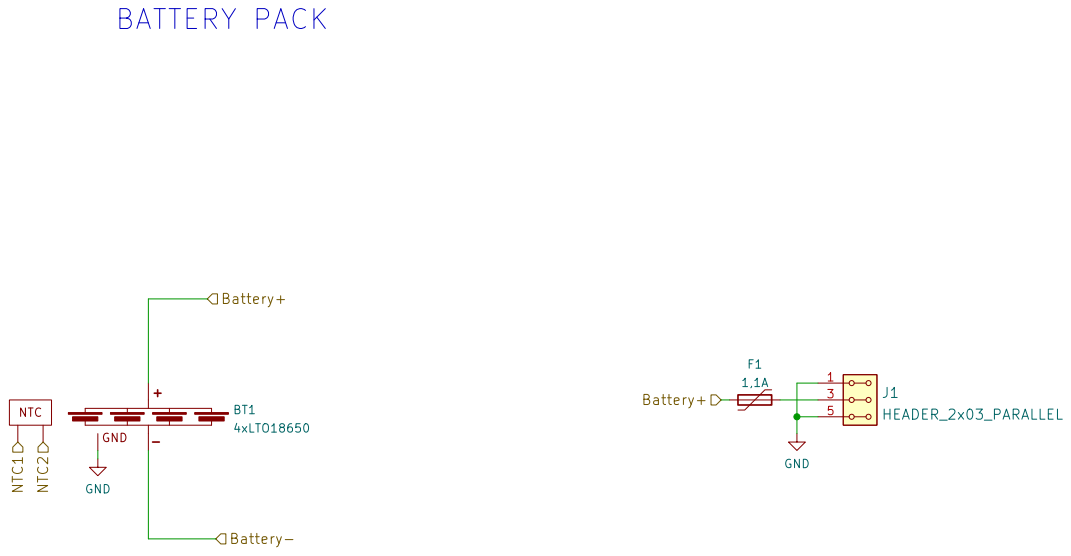
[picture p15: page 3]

Solar charged LTO Battery Managment System

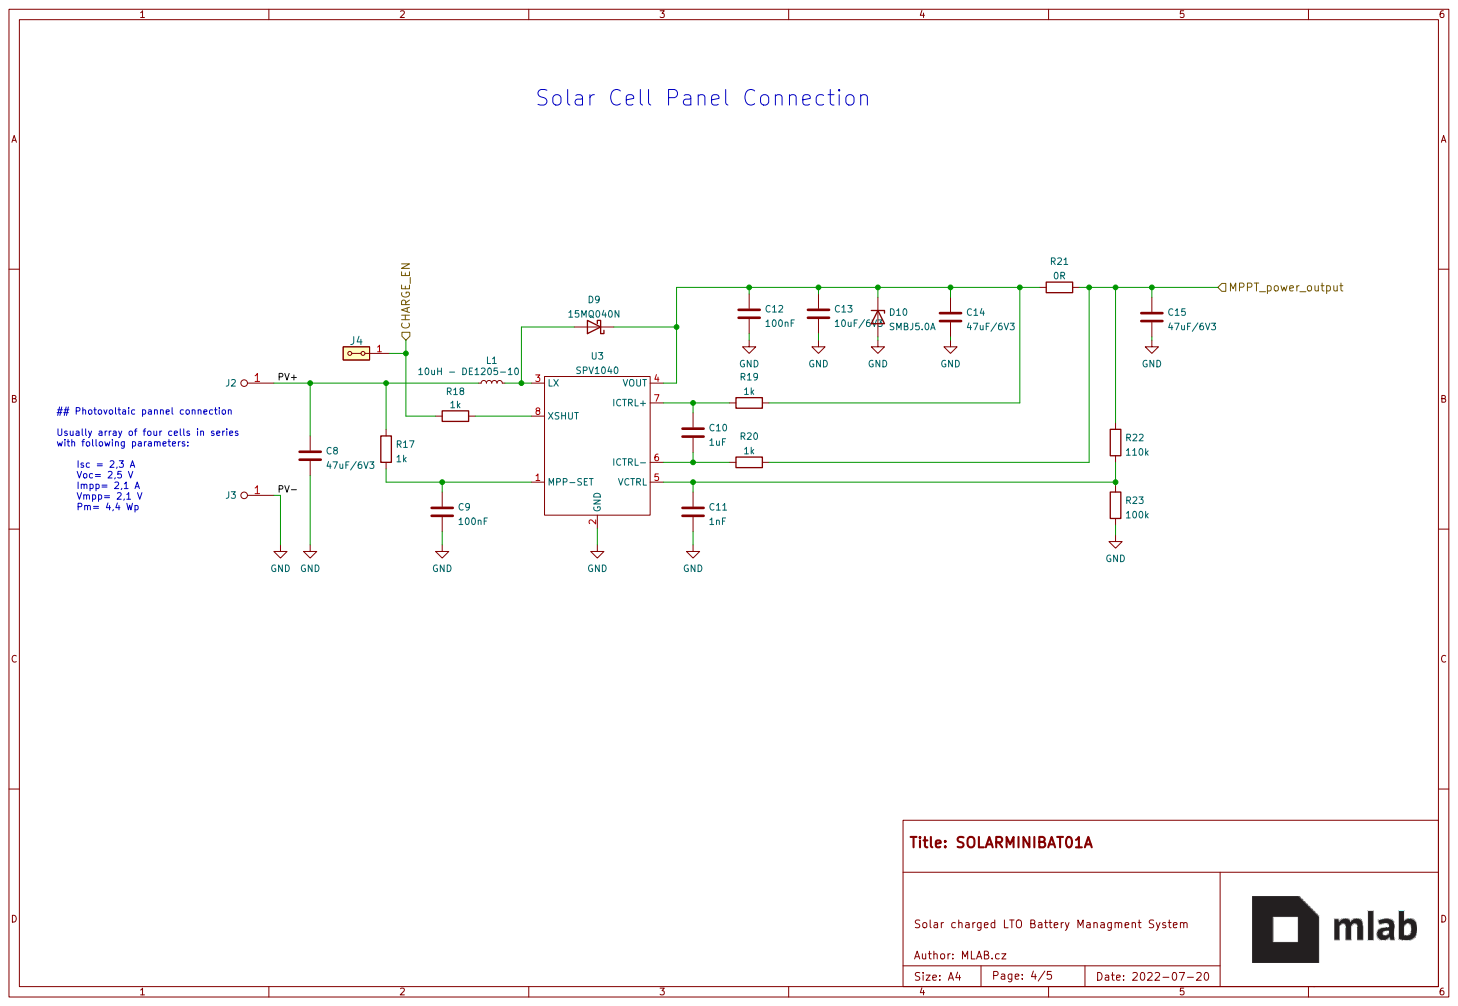
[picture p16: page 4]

Solar Cell Panel Connection

Usually array of four cells in series
with following parameters:

Solar charged LTO Battery Managment System

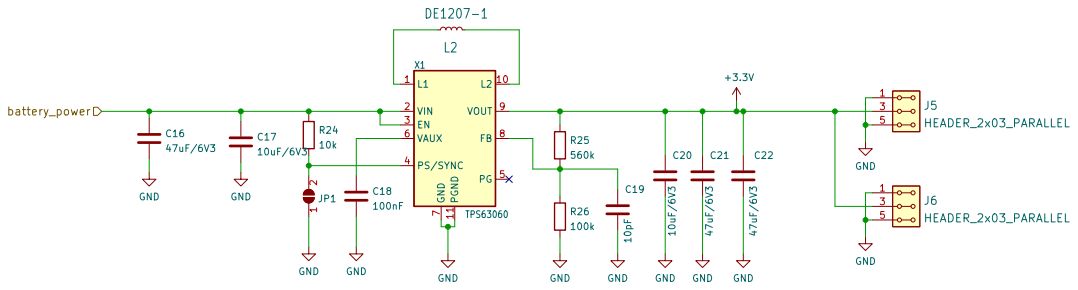
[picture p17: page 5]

Solar charged LTO Battery Managment System

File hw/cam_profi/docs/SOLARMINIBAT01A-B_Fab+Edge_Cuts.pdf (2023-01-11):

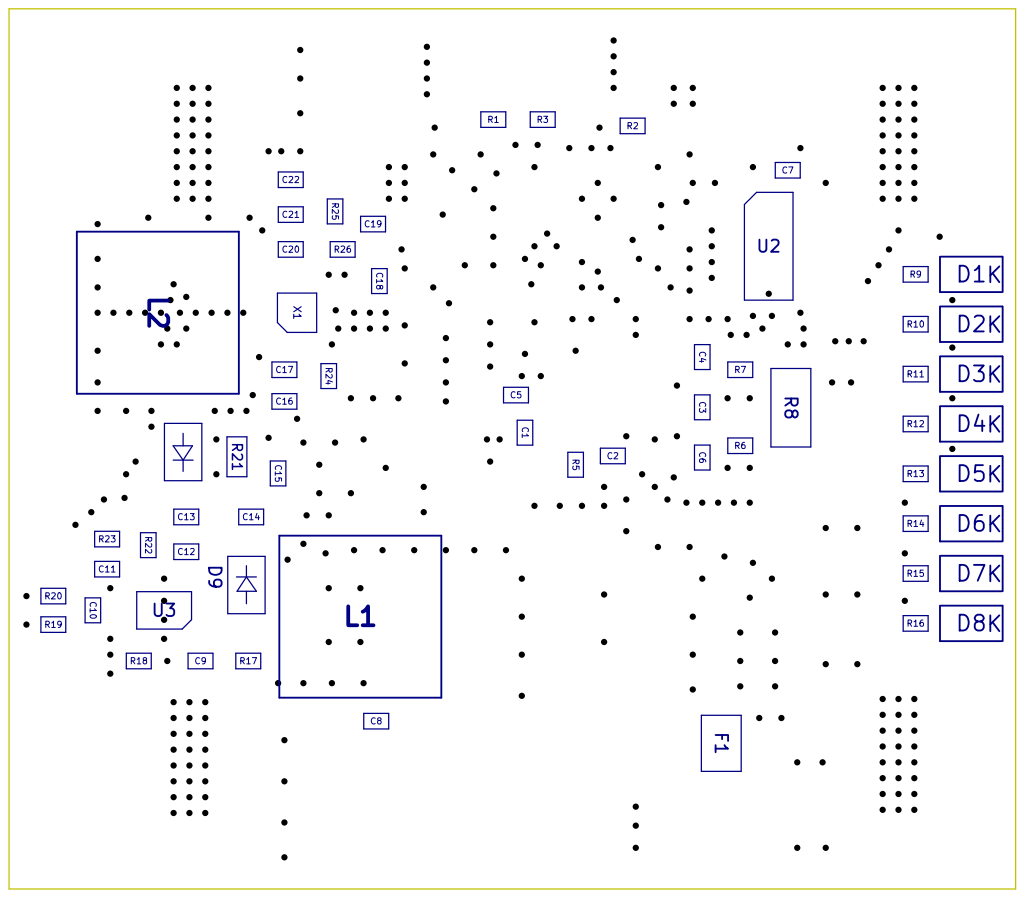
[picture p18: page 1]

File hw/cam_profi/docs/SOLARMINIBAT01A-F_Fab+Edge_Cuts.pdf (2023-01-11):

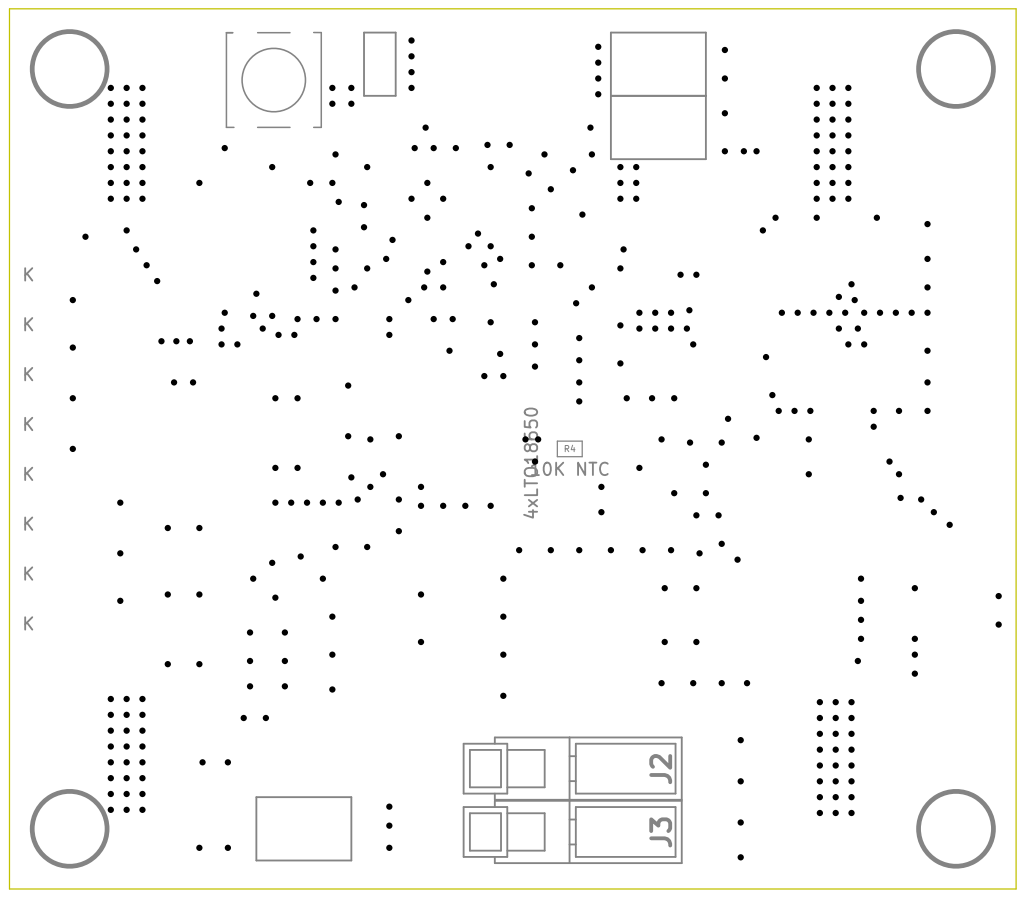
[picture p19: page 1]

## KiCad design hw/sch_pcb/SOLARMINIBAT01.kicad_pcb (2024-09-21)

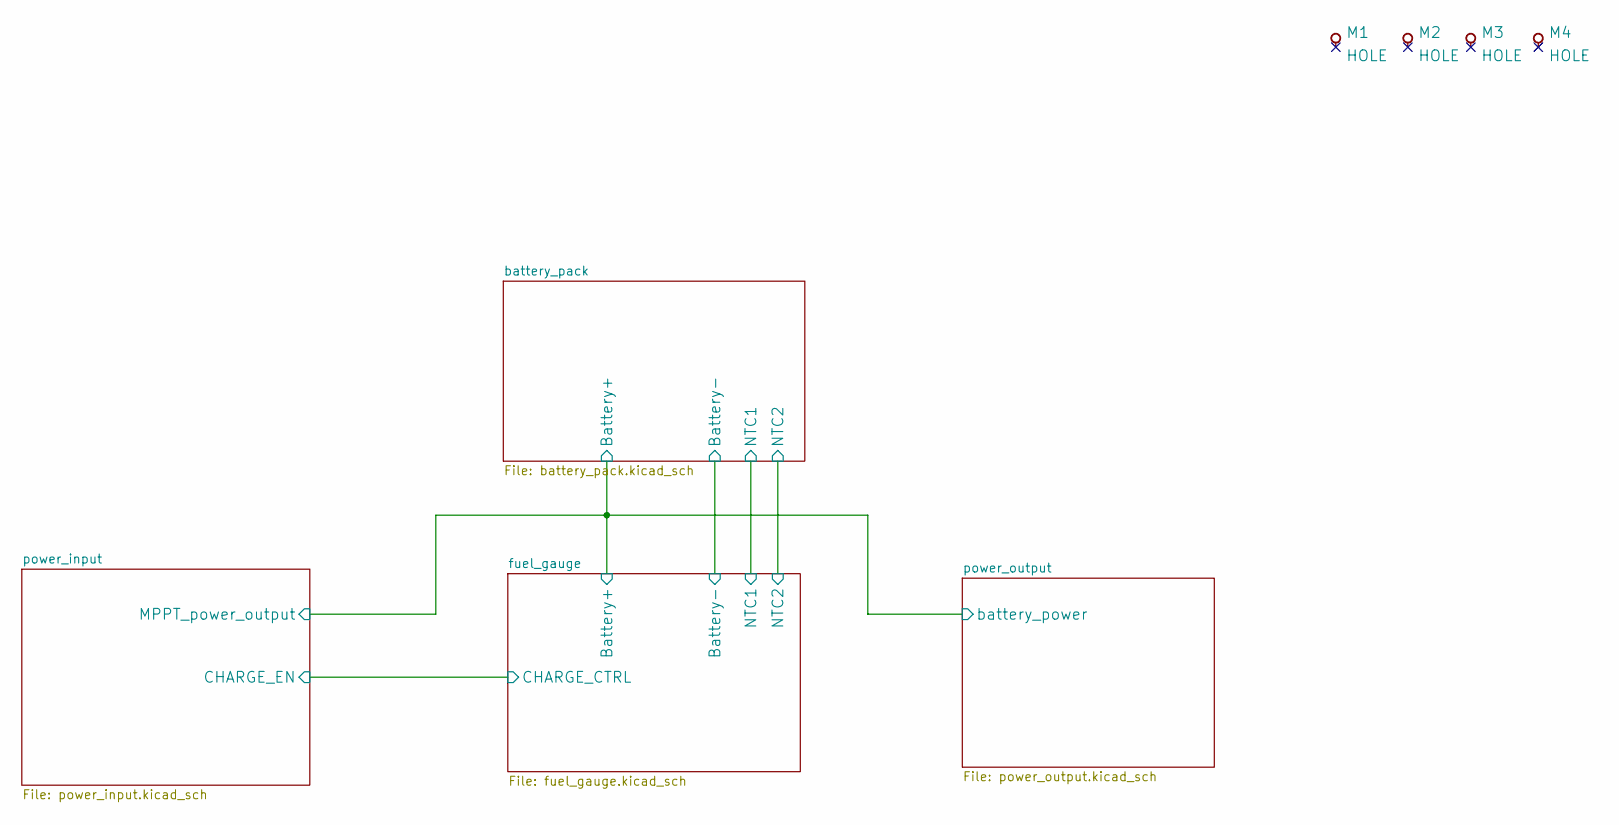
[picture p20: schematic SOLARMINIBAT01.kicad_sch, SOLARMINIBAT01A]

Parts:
M1, M2, M3, M4: HOLE; MountingHole_3mm

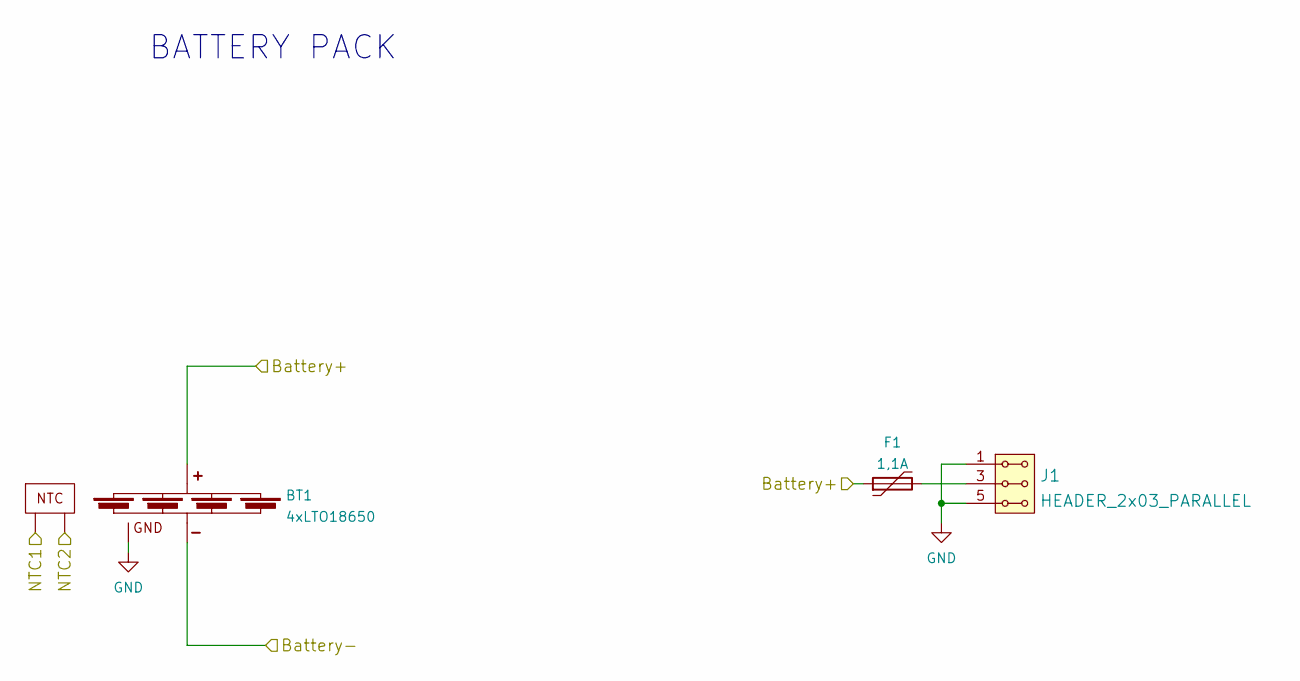
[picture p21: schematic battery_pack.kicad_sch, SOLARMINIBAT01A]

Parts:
BT1: 4xLTO18650; 4XLTO1865V01A
F1: 1,1A; Fuse_1812_4532Metric_Pad1.30x3.40mm_HandSolder
J1: HEADER_2x03_PARALLEL; Straight_2x03

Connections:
/battery_pack/Battery+: BT1.1 (+), F1.1; also elsewhere on the board
/battery_pack/Battery-: BT1.2 (-); also elsewhere on the board
/battery_pack/NTC1: BT1.5; also elsewhere on the board
/battery_pack/NTC2: BT1.6; also elsewhere on the board
GND: BT1.3 (GND), J1.1, J1.2, J1.5, J1.6; also elsewhere on the board
unnamed: F1.2, J1.3, J1.4

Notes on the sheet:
BATTERY PACK

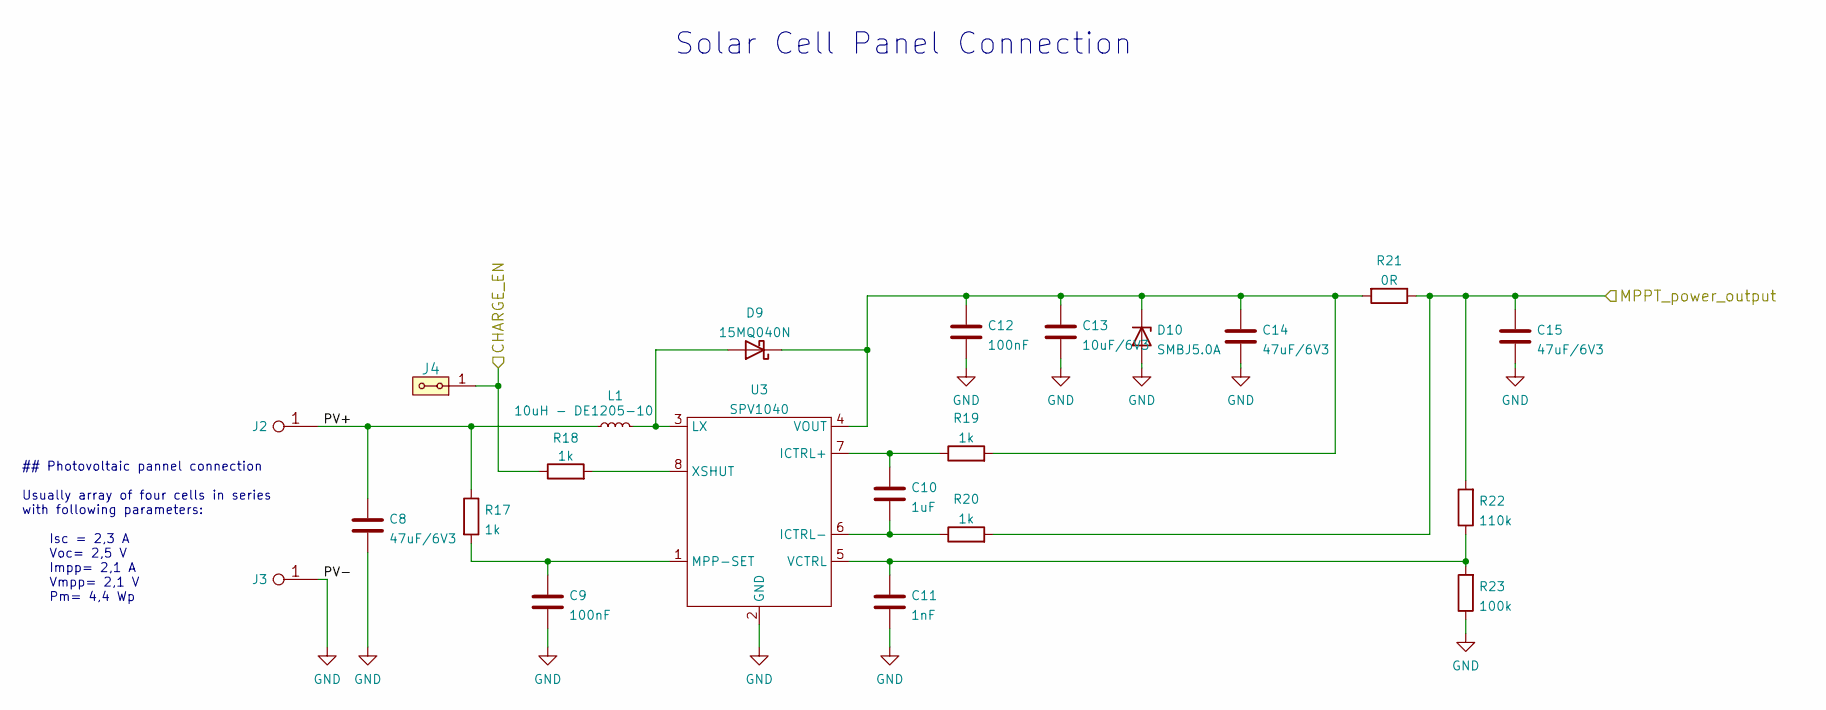
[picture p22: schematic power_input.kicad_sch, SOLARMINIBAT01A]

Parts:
C8, C14, C15: 47uF/6V3; C_0805_2012Metric
C9, C12: 100nF; C_0805_2012Metric
C10: 1uF; C_0805_2012Metric
C11: 1nF; C_0805_2012Metric
C13: 10uF/6V3; C_0805_2012Metric
D9: 15MQ040N; D_SMA
D10: SMBJ5.0A; D_SMA
J2: WAGO 256 ORANGE; WAGO256
J3: WAGO 256 BLUE; WAGO256
J4: HEADER_2x01_PARALLEL; Straight_2x01
L1: 10uH - DE1205-10; DE1205-10
R17, R18, R19, R20: 1k; R_0805_2012Metric
R21: 0R; R_1206_3216Metric
R22: 110k; R_0805_2012Metric
R23: 100k; R_0805_2012Metric
U3: SPV1040; TSSOP-8_4.4x3mm_P0.65mm

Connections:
/battery_pack/Battery+: C15.1, R20.2, R21.1, R22.2; also elsewhere on the board
/fuel_gauge/CHARGE_CTRL: J4.1, J4.2, R18.1; also elsewhere on the board
/power_input/PV+: C8.1, J2.1, L1.1, R17.1
GND: C8.2, C9.2, C11.2, C12.2, C13.2, C14.2, C15.2, D10.2 (A), J3.1, R23.1, U3.2 (GND); also elsewhere on the board
unnamed: C9.1, R17.2, U3.1 (MPP-SET)
unnamed: C10.1, R19.1, U3.7 (ICTRL+)
unnamed: C10.2, R20.1, U3.6 (ICTRL-)
unnamed: C11.1, R22.1, R23.2, U3.5 (VCTRL)
unnamed: C12.1, C13.1, C14.1, D9.1 (K), D10.1 (K), R19.2, R21.2, U3.4 (VOUT)
unnamed: D9.2 (A), L1.2, U3.3 (LX)
unnamed: R18.2, U3.8 (XSHUT)

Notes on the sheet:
## Photovoltaic pannel connection Usually array of four cells in series with following parameters: Isc = 2,3 A Voc= 2,5 V Impp= 2,1 A Vmpp= 2,1 V Pm= 4,4 Wp
Solar Cell Panel Connection

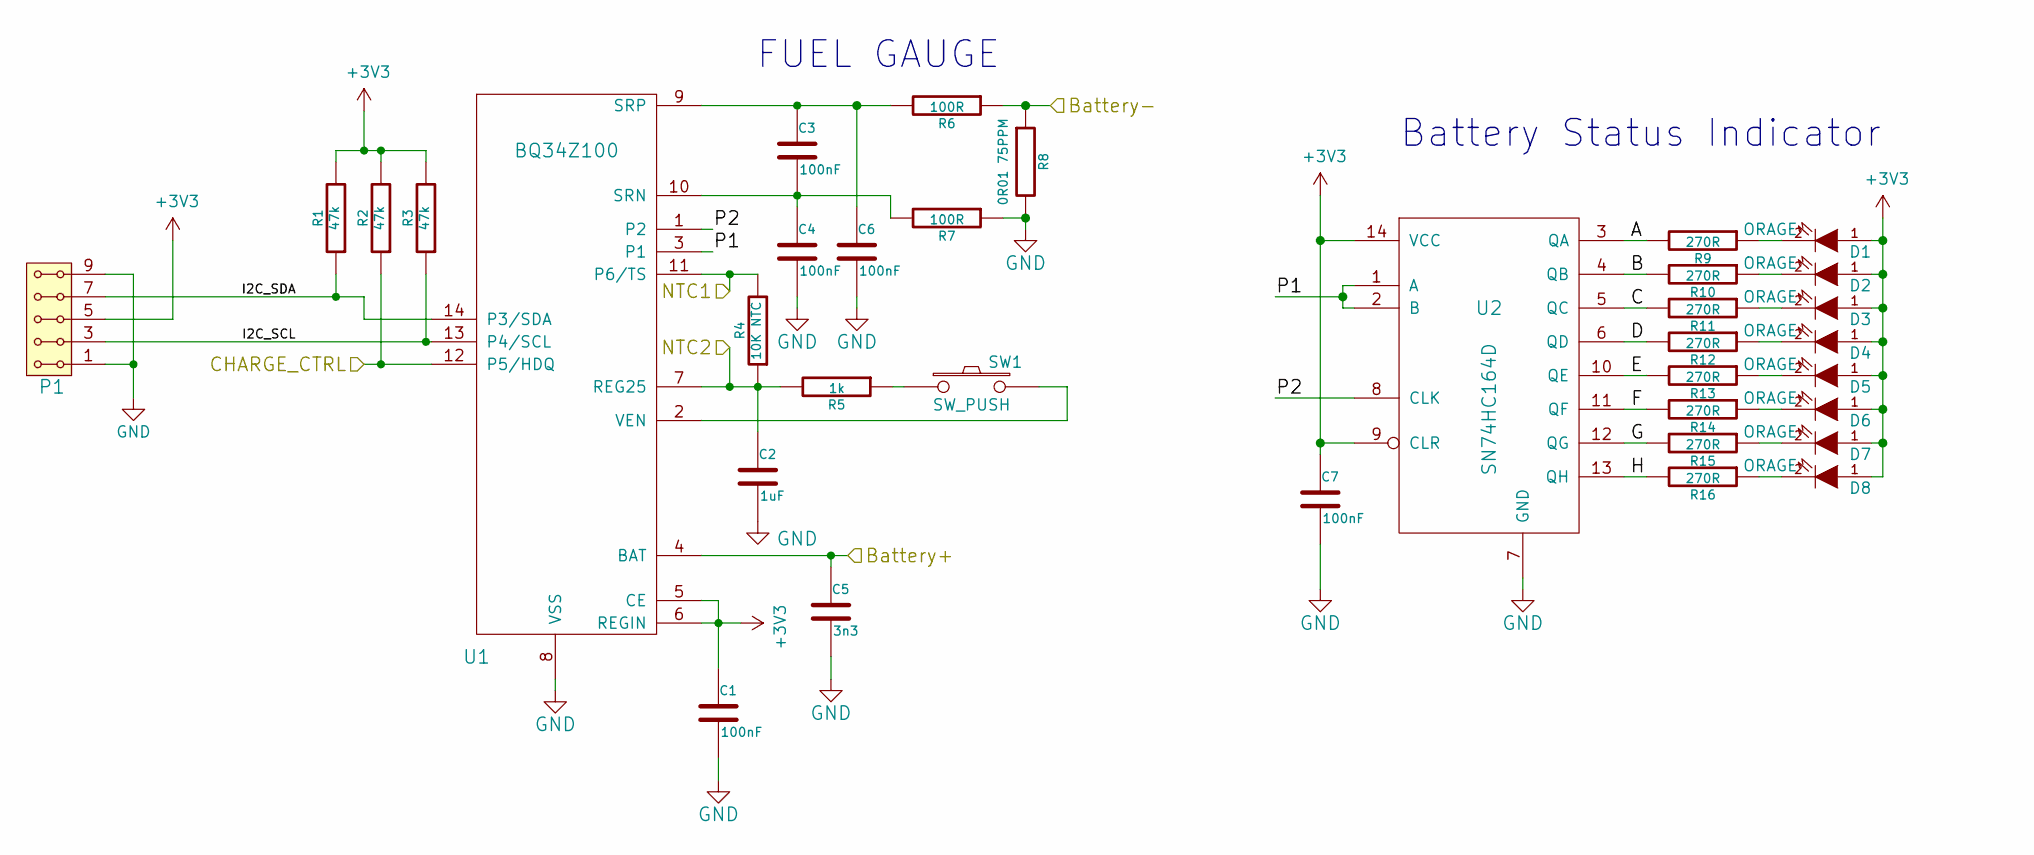
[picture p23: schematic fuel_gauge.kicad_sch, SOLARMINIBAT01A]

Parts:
C1, C3, C4, C6, C7: 100nF; C_0805_2012Metric
C2: 1uF; C_0805_2012Metric
C5: 3n3; C_0805_2012Metric
D1, D2, D3, D4, D5, D6, D7, D8: ORAGE; LED_1206
P1: HEADER_2x05_PARALLEL; Straight_2x05
R1, R2, R3: 47k; R_0805_2012Metric
R4: 10K NTC; R_0805_2012Metric_Pad1.20x1.40mm_HandSolder
R5: 1k; R_0805_2012Metric
R6, R7: 100R; R_0805_2012Metric
R8: 0R01 75PPM; R_2512_6332Metric_Pad1.40x3.35mm_HandSolder
R9, R10, R11, R12, R13, R14, R15, R16: 270R; R_0805_2012Metric
SW1: SW_PUSH; SW_PUSH_SMALL
U1: BQ34Z100; TSSOP-14_4.4x5mm_Pitch0.65mm
U2: SN74HC164D; SO-14_3.9x8.65mm_P1.27mm

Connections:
+3V3: C1.1, C7.1, D1.1 (A), D2.1 (A), D3.1 (A), D4.1 (A), D5.1 (A), D6.1 (A), D7.1 (A), D8.1 (A), P1.5, P1.6, R1.2, R2.2, R3.2, U1.5 (CE), U1.6 (REGIN), U2.9 (CLR), U2.14 (VCC); also elsewhere on the board
/battery_pack/Battery+: C5.1, U1.4 (BAT); also elsewhere on the board
/battery_pack/Battery-: R6.1, R8.1; also elsewhere on the board
/battery_pack/NTC1: R4.2, U1.11 (P6/TS); also elsewhere on the board
/battery_pack/NTC2: C2.1, R4.1, R5.2, U1.7 (REG25); also elsewhere on the board
/fuel_gauge/A: R9.2, U2.3 (QA)
/fuel_gauge/B: R10.2, U2.4 (QB)
/fuel_gauge/C: R11.2, U2.5 (QC)
/fuel_gauge/CHARGE_CTRL: R2.1, U1.12 (P5/HDQ); also elsewhere on the board
/fuel_gauge/D: R12.2, U2.6 (QD)
/fuel_gauge/E: R13.2, U2.10 (QE)
/fuel_gauge/F: R14.2, U2.11 (QF)
/fuel_gauge/G: R15.2, U2.12 (QG)
/fuel_gauge/H: R16.2, U2.13 (QH)
/fuel_gauge/I2C_SCL: P1.3, P1.4, R3.1, U1.13 (P4/SCL)
/fuel_gauge/I2C_SDA: P1.7, P1.8, R1.1, U1.14 (P3/SDA)
/fuel_gauge/P1: U1.3 (P1), U2.1 (A), U2.2 (B)
/fuel_gauge/P2: U1.1 (P2), U2.8 (CLK)
GND: C1.2, C2.2, C4.2, C5.2, C6.2, C7.2, P1.1, P1.2, P1.9, P1.10, R7.1, R8.2, U1.8 (VSS), U2.7 (GND); also elsewhere on the board
unnamed: C3.1, C6.1, R6.2, U1.9 (SRP)
unnamed: C3.2, C4.1, R7.2, U1.10 (SRN)
unnamed: D1.2 (K), R9.1
unnamed: D2.2 (K), R10.1
unnamed: D3.2 (K), R11.1
unnamed: D4.2 (K), R12.1
unnamed: D5.2 (K), R13.1
unnamed: D6.2 (K), R14.1
unnamed: D7.2 (K), R15.1
unnamed: D8.2 (K), R16.1
unnamed: R5.1, SW1.1
unnamed: SW1.2, U1.2 (VEN)

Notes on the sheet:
Battery Status Indicator
FUEL GAUGE

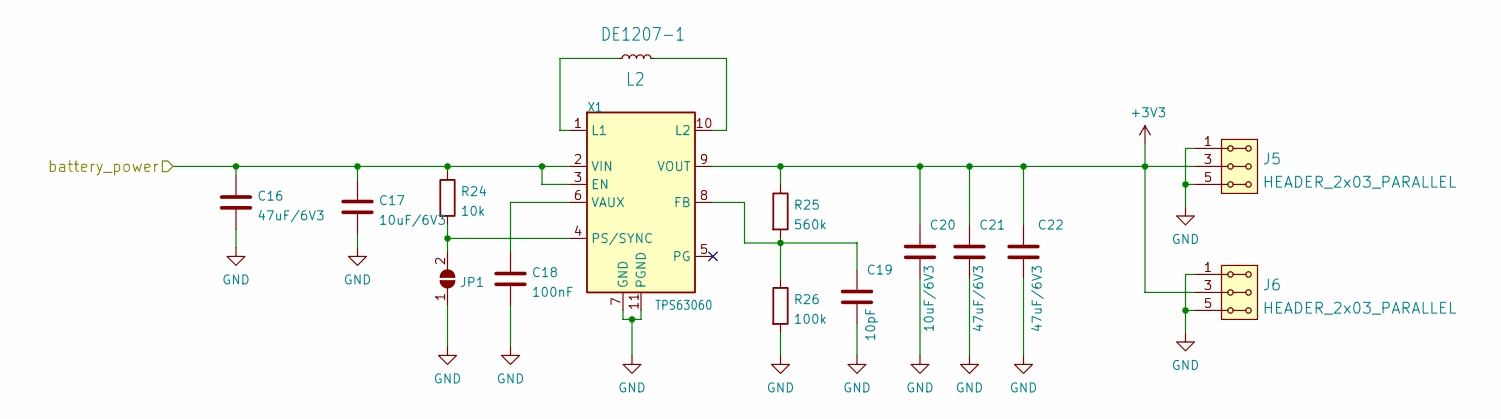
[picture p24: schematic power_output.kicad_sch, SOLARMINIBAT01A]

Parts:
C16, C21, C22: 47uF/6V3; C_0805_2012Metric
C17, C20: 10uF/6V3; C_0805_2012Metric
C18: 100nF; C_0805_2012Metric
C19: 10pF; C_0805_2012Metric
J5, J6: HEADER_2x03_PARALLEL; Straight_2x03
JP1: SolderJumper_2_Open; SolderJumper-2_P1.3mm_Open_RoundedPad1.0x1.5mm
L2: DE1207-1; DE1205-10
R24: 10k; R_0805_2012Metric
R25: 560k; R_0805_2012Metric
R26: 100k; R_0805_2012Metric
X1: TPS63060; Texas_S-PWSON-N10_ThermalVias

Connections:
+3V3: C20.1, C21.1, C22.1, J5.3, J5.4, J6.3, J6.4, R25.1, X1.9 (VOUT); also elsewhere on the board
/battery_pack/Battery+: C16.1, C17.1, R24.1, X1.2 (VIN), X1.3 (EN); also elsewhere on the board
GND: C16.2, C17.2, C18.2, C19.2, C20.2, C21.2, C22.2, J5.1, J5.2, J5.5, J5.6, J6.1, J6.2, J6.5, J6.6, JP1.1 (A), R26.2, X1.7 (GND), X1.11 (PGND); also elsewhere on the board
unnamed: C18.1, X1.6 (VAUX)
unnamed: C19.1, R25.2, R26.1, X1.8 (FB)
unnamed: JP1.2 (B), R24.2, X1.4 (PS/SYNC)
unnamed: L2.1, X1.1 (L1)
unnamed: L2.2, X1.10 (L2)

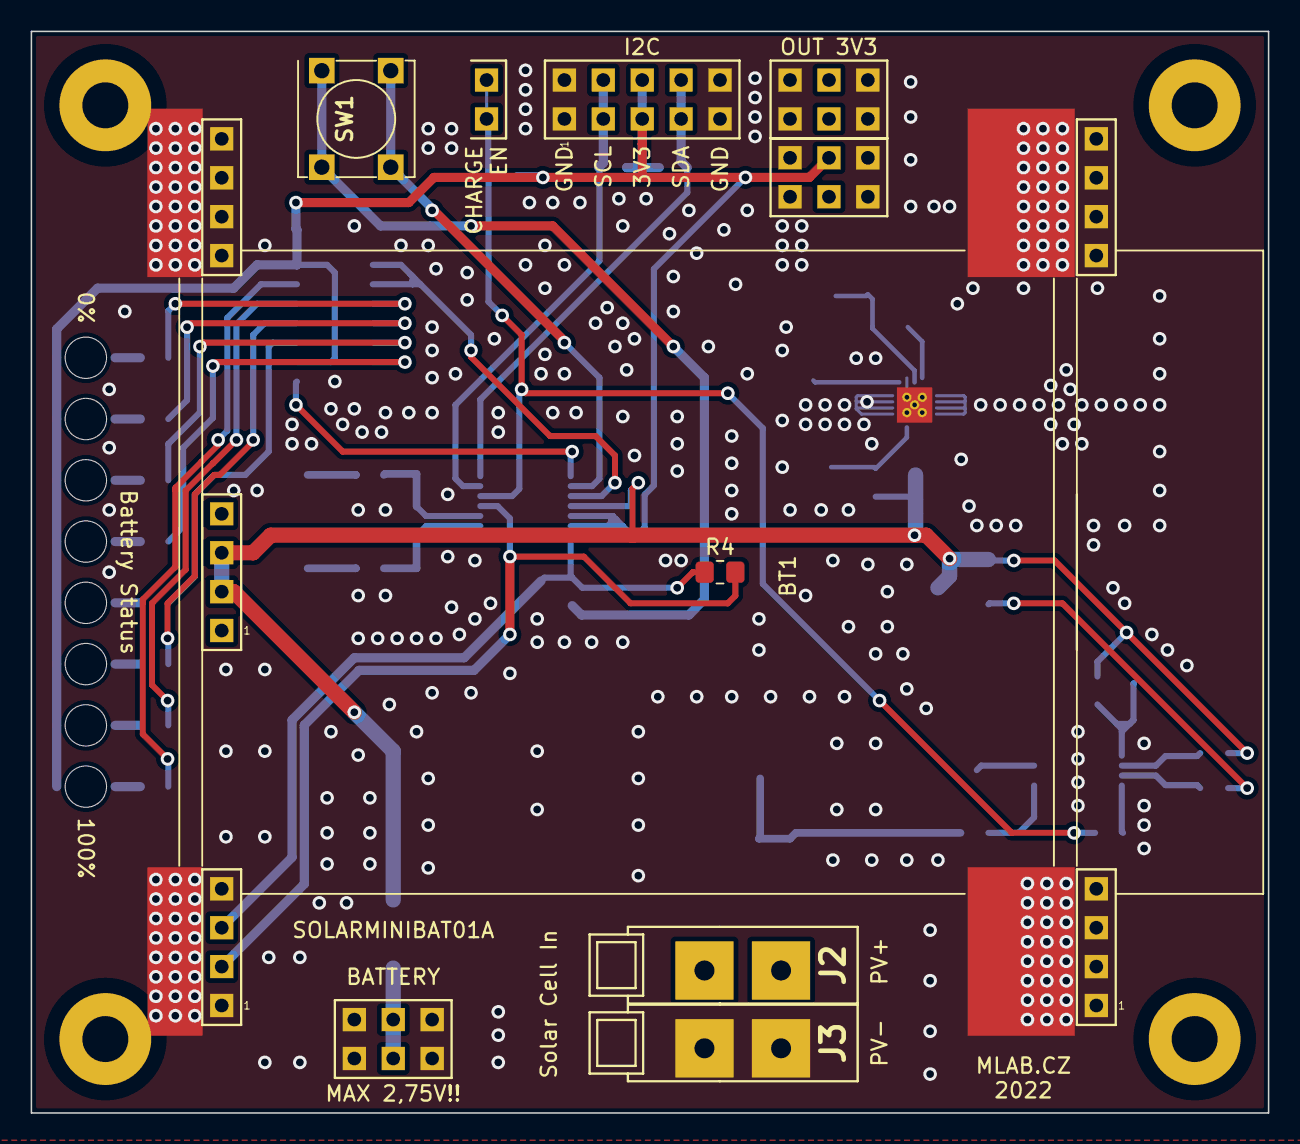
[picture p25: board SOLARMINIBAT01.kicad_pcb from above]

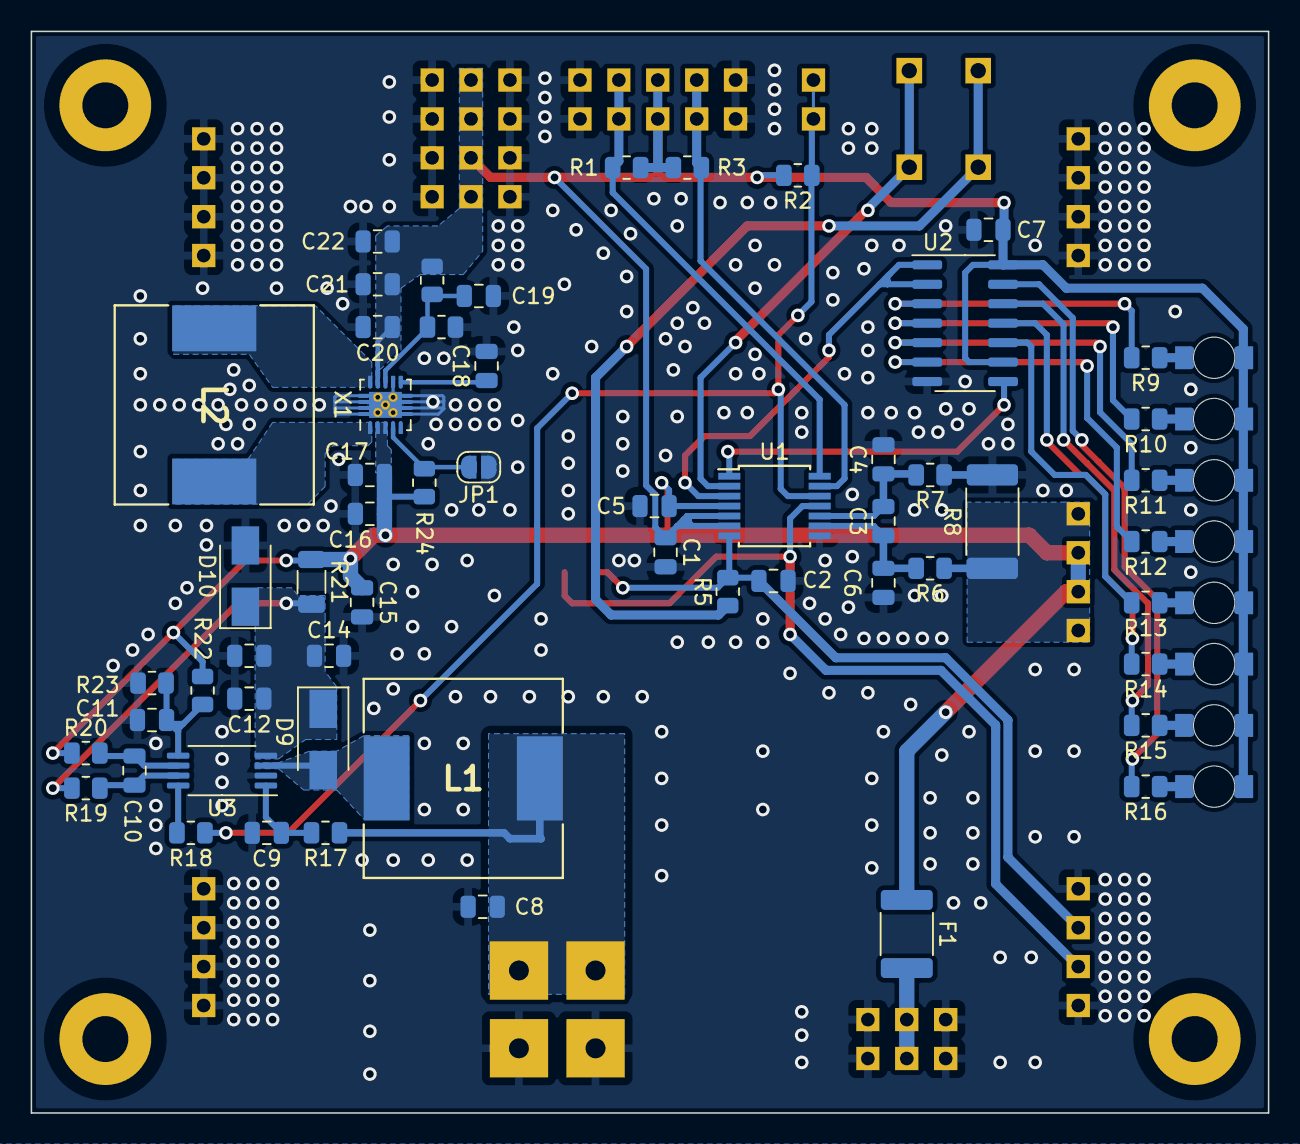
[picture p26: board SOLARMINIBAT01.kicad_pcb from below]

Board: 2 copper layers, 80.8 x 70.6 mm, 79 parts (65 on the bottom side), 45 nets.

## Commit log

2022-07-20 start design of new module
    [SOLARMINIBAT01.kicad_pcb, SOLARMINIBAT01.kicad_sch, battery_pack.kicad_sch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]
2022-07-20 Prejmenovani projektu Kicad
    [SOLARMINIBAT01A.kicad_pcb, SOLARMINIBAT01A.kicad_sch]
2022-07-20 Pridano schema menice ze solarniho clanku
    [SOLARMINIBAT01A.kicad_sch, fuel_gauge.kicad_sch, solar_converter.kicad_sch]
2022-07-20 Adding input switching regulator.
    [SOLARMINIBAT01.kicad_sch, battery_pack.kicad_sch, fuel_gauge.kicad_sch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]
2022-07-20 cleanup unused file.
    [SOLARMINIBAT01A.kicad_sch, fuel_gauge.kicad_sch, power_input.kicad_sch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]
2022-07-20 finish gauge schematics design.
    [SOLARMINIBAT01A.kicad_sch, battery_pack.kicad_sch, fuel_gauge.kicad_sch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]
2022-07-20 Edit schema
    [SOLARMINIBAT01A.kicad_sch, power_output.kicad_sch]
2022-07-21 Update schematics: Adding datasheet Update title blocks Update pull-up value for CHARGE_CTRL signal.
    [SOLARMINIBAT01A.kicad_sch, battery_pack.kicad_sch, fuel_gauge.kicad_sch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]
2022-07-25 Edit PCB
    [SOLARMINIBAT01A.kicad_pcb, SOLARMINIBAT01A.kicad_sch, battery_pack.kicad_sch]
2022-08-10 Edit kicad_outputs.yml
2022-08-10 Update actions products
    [SOLARMINIBAT01A-B_Adhesive.dxf, SOLARMINIBAT01A-B_Courtyard.dxf, SOLARMINIBAT01A-B_Cu.dxf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]
2022-08-15 Edit UST ID
    [SOLARMINIBAT01A.kicad_sch, battery_pack.kicad_sch, fuel_gauge.kicad_sch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]
2022-08-16 Editing FAB layer
    [SOLARMINIBAT01A.kicad_pcb]
2023-01-11 Add a link to diode datasheet.
    [power_input.kicad_sch]
2023-01-15 battery printed holder - source
    [battery_holder.3mf, battery_holder.scad, battery_holder.stl]
2023-07-05 automated commit; rename source files to new naming convence
    [SOLARMINIBAT01.kicad_pcb, SOLARMINIBAT01.kicad_sch]
2023-07-25 battery contacts cover
    [battery_cover.scad, battery_cover.stl, battery_cover_text.stl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]
2024-09-21 Add datasheet to the used LTO cells. Improve documentation, update KiCAD project.
    [SOLARMINIBAT01.kicad_pcb, SOLARMINIBAT01.kicad_sch, battery_pack.kicad_sch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]
2024-09-29 Improved documentation and schematics. Output divider values changed to better fit maximum cell voltage.
    [power_input.kicad_sch]
